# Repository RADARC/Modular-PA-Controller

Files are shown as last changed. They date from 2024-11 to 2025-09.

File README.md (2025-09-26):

# Modular-PA-Controller
Controller for High Power RF Power Amplifiers based Raspberry Pi Pico

Reading and District Amateur Radio Club(RADARC) are working together on a number of collaborative construction projects. This one is to design and build a Modular PA controller for High Power (1kW plus) semiconductor Power amplifiers.
This prototype implementation is targetted on the High Power HF PA Modules from [W6PQL](https://www.w6pql.com/) :

* [Kilowatt PA](https://www.w6pql.com/1_kw_sspa_for_1_8-54_mhz.htm)
* [LPF Filter](https://www.w6pql.com/a_1.5kw_lpf_for_160-6m.htm)
* [Directional Coupler](https://www.w6pql.com/1_8_to_54_mhz_dual_coupler.htm)

## Objectives:
<ul>
<li><strong>Protection</strong></li>
<ul>
<li>Protection of user and premises</li>
<li>Protection of Power Amplifier</li>
<li>Protection of connected equipment</li>
</ul>
<li><strong>Automatic Operation and Sequencing</strong>
<ul>
<li>Monitoring of Power Amplifier operational state</li>
<li>Control of operational components of Power Amplifier</li>
<li>Detection of state of connected equipment</li>
<li>Sequencing and crystal controlled timing of sequencing</li>
</ul>
<li><strong>Power Supplies</strong></li>
<ul>
<li>Low voltage power supplies derived from High Voltage PA supply</li>
<li>Variable Vgg Bias voltage supply</li>
</ul>
<li><strong> External control and Monitoring</strong></li>
<ul>
<li>LCD Display</li>
<li>USB</li>
<li>TTL Serial</li>
<li>Wifi and Bluetooth</li>

</ul>
</ul>

## Specification
<ul>
<li>Processor: Raspberry Pi Pico</li>
<li>Maximum input Voltage: 72V DC</li>
<li>Maximum switched PA current: 50A</li>
<li>Vgg bias output range: 1.4V to 4.7V</li>
<li>Number of PWM and RPM monitored fans(5V or 12V): 3</li>
<li>Number of voltage controlled fans: 1</li>
<li>Number of directional coupler inputs: 3</li>
<li>Analogue meter outputs: 2
<li>Transceiver ALC output: -12V to +12V</li>
<li>Transceiver digital SEND in/out Ports: 1</li>
<li>OLED control ports: 1</li>
<li>Rotary Encoders: 2</li>
<li>OLED control ports: 1</li>
<li>Input frequency measurement range: 100kHz to 50MHz</li>
<li>Input Power detection: 10dBm to 50dBm</li>
<li>Maximum input Power Tx/RX switching: 50dBm</li>
<li>Output TX/RX relay drivers(5V or 12V): 2</li>
<li>Output LPF relay drivers(%V or 12V): 6</li>
<li>I2C ports: 1</li>
<li>TTLserial ports: 1</li>                                                                                               
</ul>

## Hardware Implementation

The Modular PA Controller Is built around four PCB assemblies:

### Power Supply and Control Board
This board manages the high DC voltage (up to 72V) part of the PA controller. It provides switching of the DC supply up to 50A, also current monitoring and Voltage monitoring. The DC supply switching uses a watchdog an requires the processor to signal the switch every 500uS to keep the power on.
It derives two lower voltage power supplies at 12V 2A and 5V 1A. The 3.3V logic supply for th PA controller is provided by the regulator on the Pi Pico on the processor board.To control the Vgg Bias to the Power Amplifier Modules the board provides either a switched 12V supply to a regulator on the Power Amplifier Board, and also a variable voltage software controlled DC output.
All control and monitoring is via I2C control from the Processor Board.

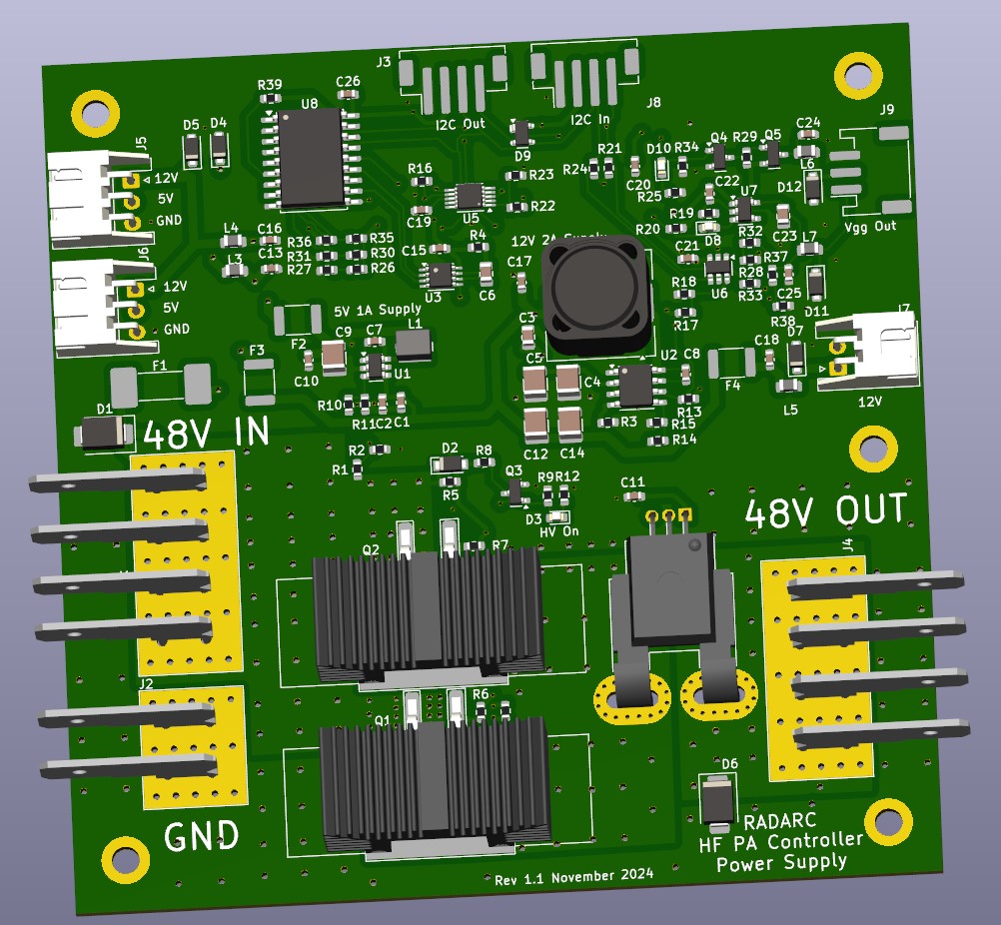
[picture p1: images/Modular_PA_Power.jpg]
Power Supply 3D


[Kicad Files](./Kicad/PA_Power_V1/)

### Processor and Interface Board
This board contains the Raspberry Pi Pico microcontroller module. The module alo provides the 3.3V logic supply and the USB interface. Pi Pico modules with Bluetooth and Wi-fi may be used, also the higher performance RP2350 version.

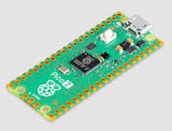
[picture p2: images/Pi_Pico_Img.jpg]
Pi Pico Image


[Pi Pico Data sheet](https://datasheets.raspberrypi.com/pico/pico-datasheet.pdf)

The board has two I2C buses. The internal bus connects to the on board ADC and DAC devices. The external I2C bus connects to the Power Supply and Control board(s), the Relay Driver board(s), LM75 temperature sensors, I2C OLED display, etc.

The board has an input TX/RX relay to bypass the Power Amplifier Modules as required.

### Relay Driver Board

### RF screen

## Software Implementation

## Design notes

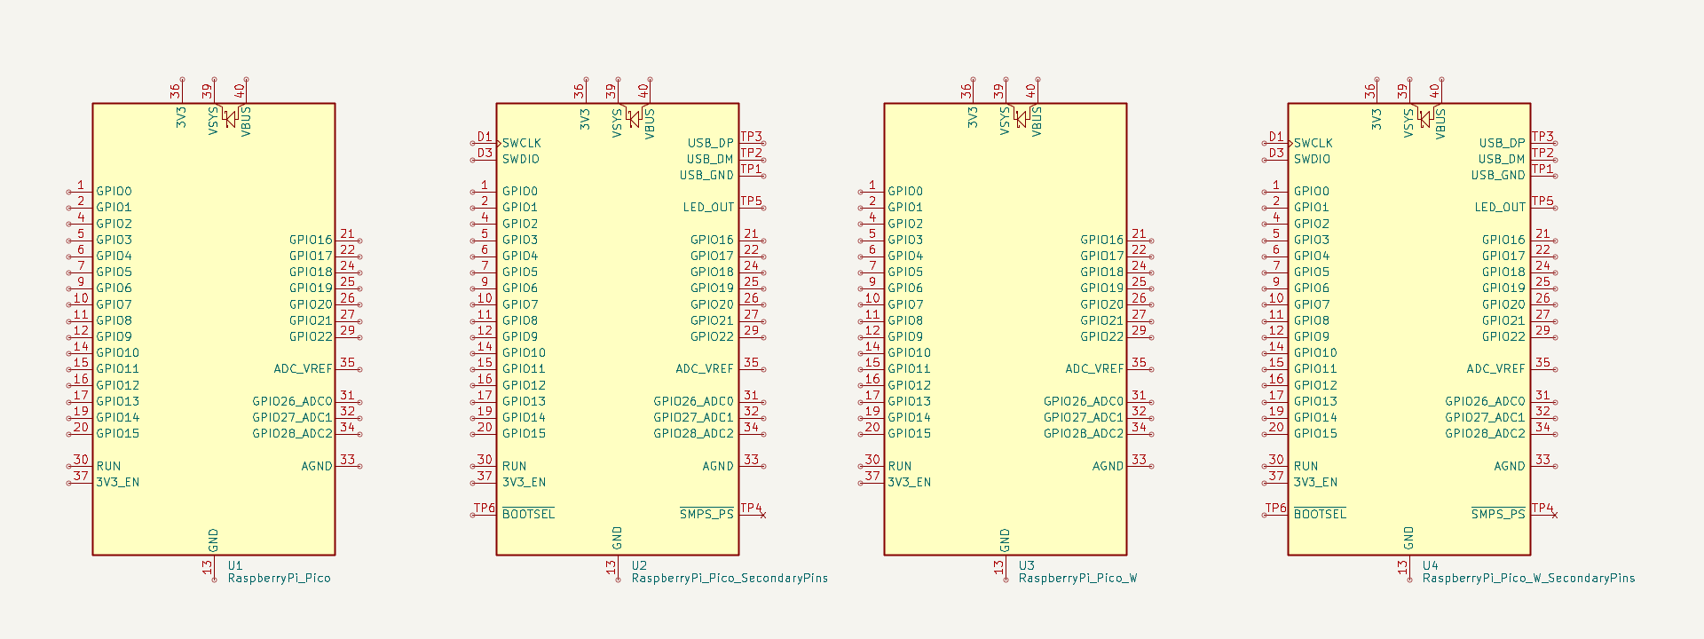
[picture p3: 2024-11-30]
Kicad/PA_Power_V1/RLab Keyboard/ki-lime-pi-pico-2.1.2/_md-assets/images/schematics.png

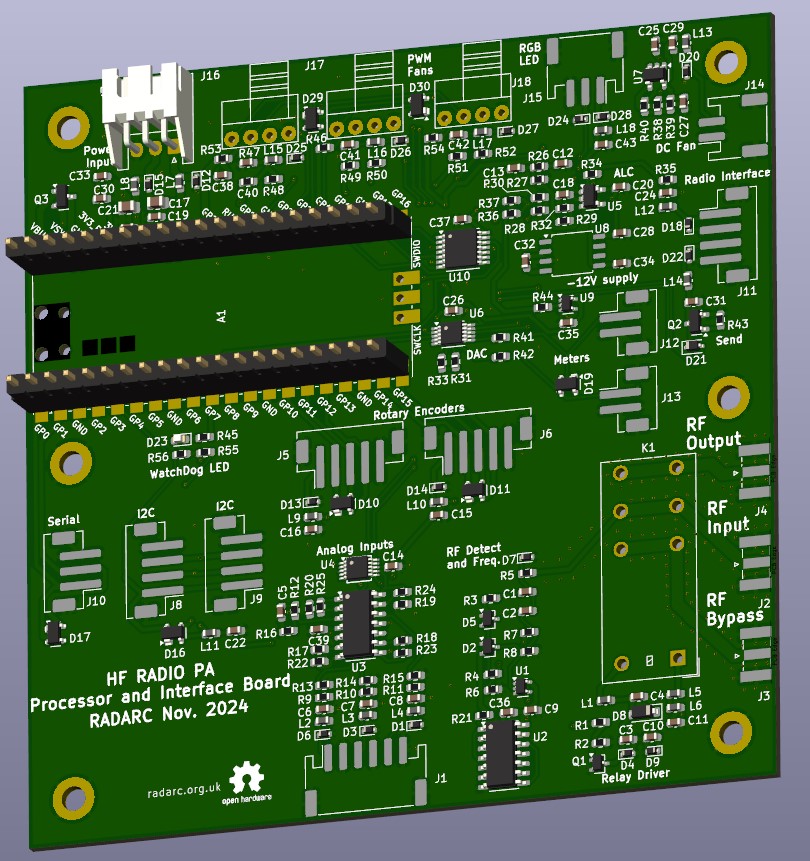
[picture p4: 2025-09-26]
images/Processor.jpg

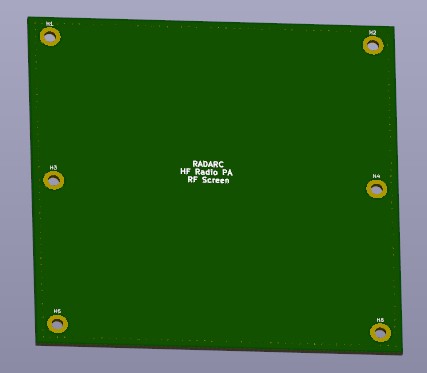
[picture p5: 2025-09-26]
images/RF_Screen.jpg

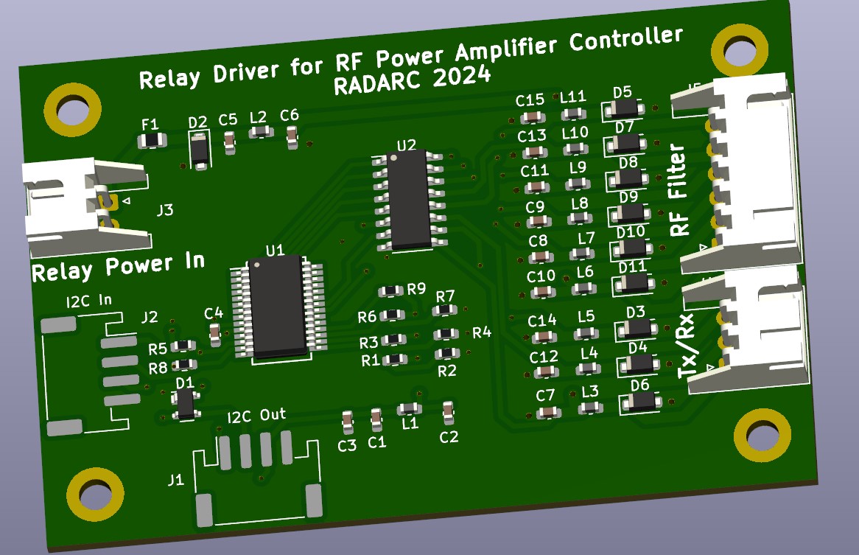
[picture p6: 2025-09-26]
images/Relay Driver.jpg

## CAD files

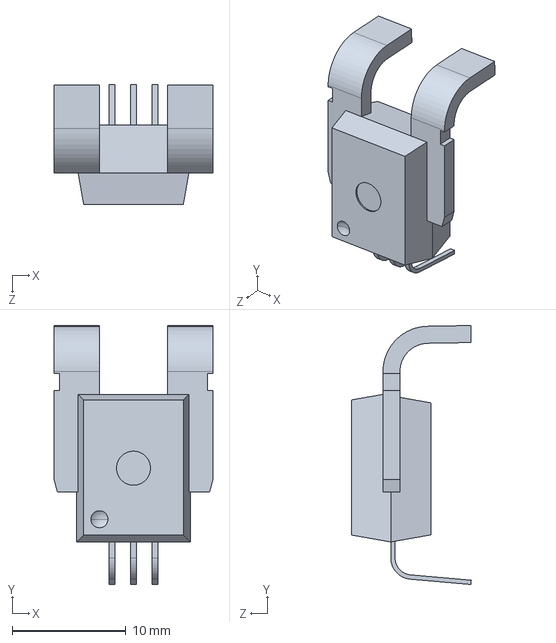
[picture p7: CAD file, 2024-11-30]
Kicad/PA_Power_V1/ACS758LCB-100B-PFF-T.stp
14.0 x 22.8 x 10.5 mm

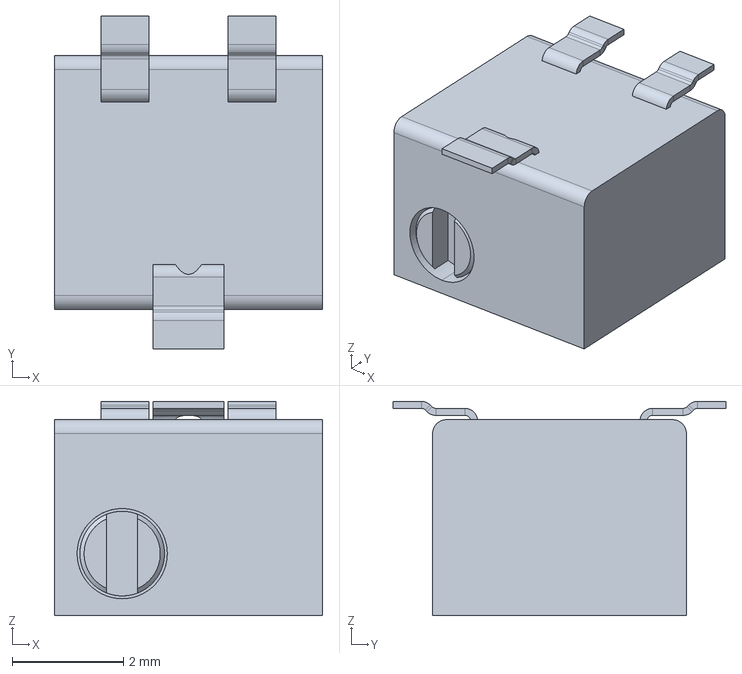
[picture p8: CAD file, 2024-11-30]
Kicad/PA_Power_V1/RLab Keyboard/3D_Models/3214G.stp
4.83 x 5.99 x 3.86 mm

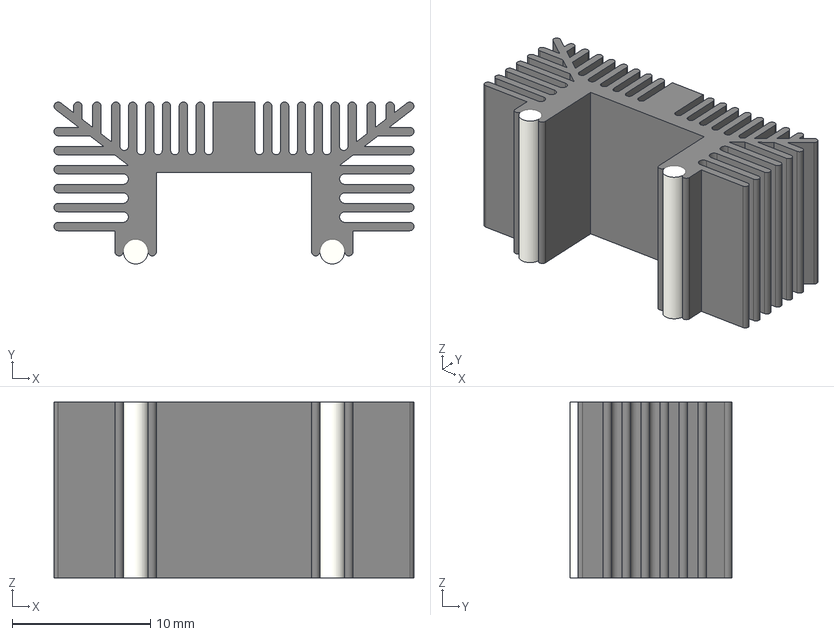
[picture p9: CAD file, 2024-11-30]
Kicad/PA_Power_V1/ohmite_DA-T263-401E-TR.stp
26.0 x 11.7 x 12.7 mm

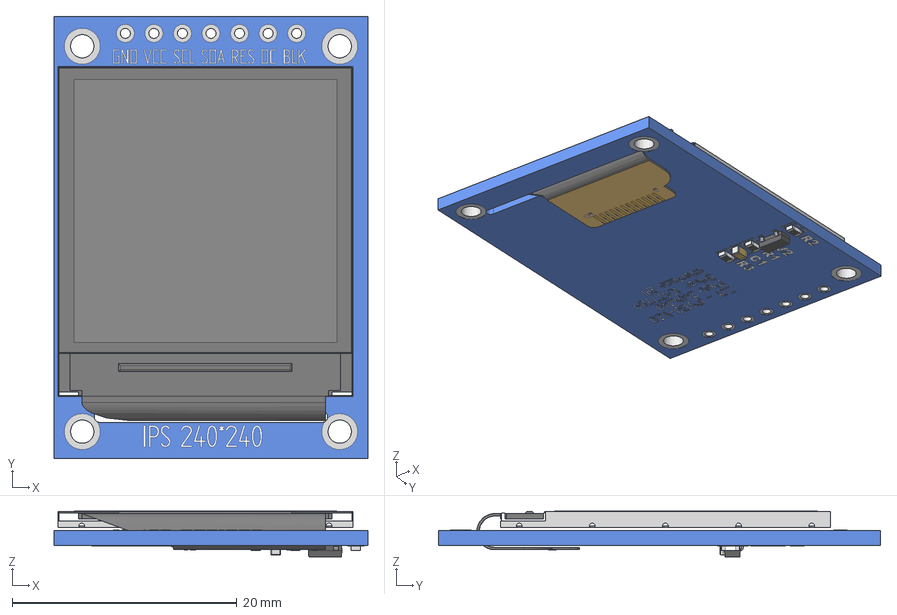
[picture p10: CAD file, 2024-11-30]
Kicad/PA_Power_V1/RLab Keyboard/3D_Models/1.3 TFT IPS.stp
27.9 x 39.4 x 4.06 mm
1.3 TFT IPS - Board
1.3 TFT IPS - Flush Reverse Mount
0603 Resistor x 3
0603 Capacitor
SOT-23

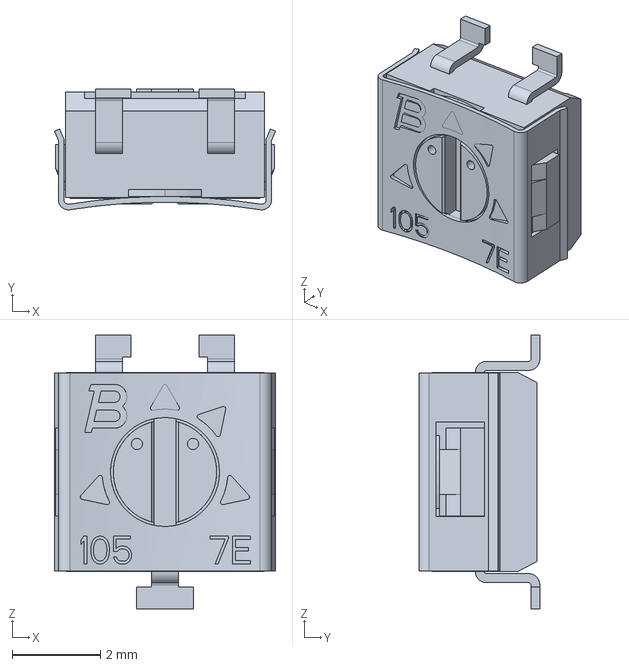
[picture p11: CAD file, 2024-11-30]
Kicad/PA_Power_V1/RLab Keyboard/3D_Models/3314G1.stp
5.00 x 2.73 x 6.20 mm

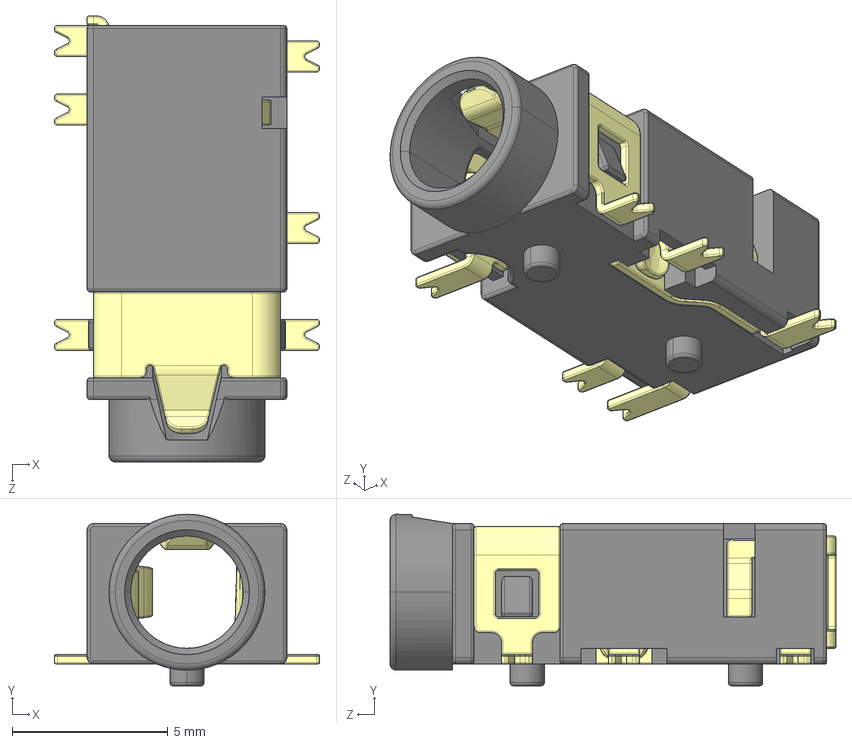
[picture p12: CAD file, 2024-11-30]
Kicad/PA_Power_V1/RLab Keyboard/3D_Models/PJ311D_WPos.STEP
8.50 x 5.50 x 14.3 mm
001^PJ311D_WPos
002^PJ311D_WPos
003^PJ311D_WPos
004^PJ311D_WPos
005^PJ311D_WPos
006^PJ311D_WPos
007^PJ311D_WPos

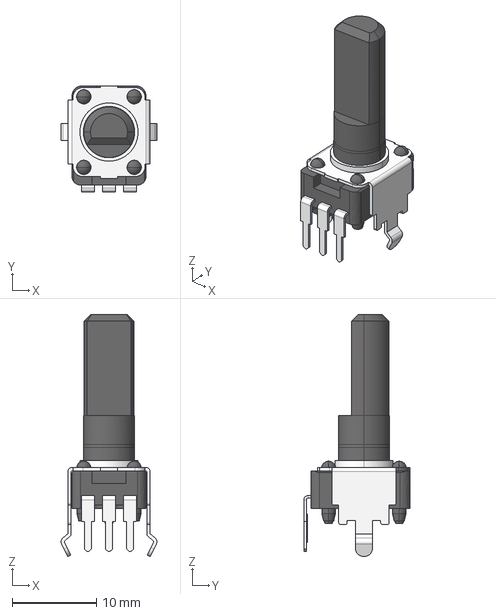
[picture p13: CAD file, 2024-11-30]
Kicad/PA_Power_V1/RLab Keyboard/3D_Models/RK09K1130AH1.STEP
11.4 x 12.7 x 28.8 mm

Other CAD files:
Kicad/PA_Power_V1/RLab Keyboard/KiCad-RP-Pico/SketchUp Model/Pico.skp

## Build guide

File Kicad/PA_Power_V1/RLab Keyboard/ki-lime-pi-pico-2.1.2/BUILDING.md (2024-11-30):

**Instructions for building from source**
===========================================

> *Note that this project was largely leveraged for becoming more familiar with various aspects of KiCad, FreeCAD, and the Raspberry Pi Pico, and certain files may use exploratory workflows as a result.*

&nbsp;

# Development Environment

  Parametric models exported using [FreeCAD 0.21.2](https://github.com/FreeCAD/FreeCAD/releases/tag/0.21.2) with the [KiCad StepUp 12.2.6](https://github.com/easyw/kicadStepUpMod/tree/a7da10da12e405d106e1e9eb551444a289859ee8) workbench addon

  If you plan on committing changes to the .FCStd document and want (somewhat) trackable commits, then from the repository root call:

  ```bash
  mkdir -p .git/hooks
  cp .githooks/pre-commit.sh .git/hooks/pre-commit
  git config --local core.hooksPath .git/hooks
  ```

  *(If you are already using a `pre-commit` git hook, then manually add the content of `pre-commit.sh` to the existing hook instead)*

  > *Copying the file at a known state curbs the security concerns of remote changes to a hook.  Always audit scripts before using them.*

  Exported VRML models modified in [VSCodium 1.74.3](https://github.com/VSCodium/vscodium/releases/tag/1.74.3.23010)

  KiCad symbols and footprints exported using [KiCad 8.0.3](https://github.com/KiCad/kicad-source-mirror/releases/tag/8.0.3)

&nbsp;

# Symbols and Footprints

  KiCad symbols and footprints are already in the appropriate directories, so nothing needs to be done to prepare them for export.

&nbsp;

# Models

<details><summary>Regarding parametric colours</summary>
  
  > *Model faces are parametrically coloured via boolean operations between parts of varying diffuse colours.  To alter source colours for the board, see `Parametric_Source > Boards_Source > Parametric Board Colour Sources` in the `Tree view` panel and modify each Body's `Appearance`.  To alter source colours for components, be sure to modify the `Appearance` of the source Bodies **directly**, which are contained within the compounds/part containers in `Parametric_Source > Pico_Components_Source`.  Modifying the `Appearance` of the compounds/part containers or setting parts' face colours with `Set Colors...` will **not** parametrically populate.*
  >
  > *Note that as of FreeCAD 0.20.2 changing the sources of the colours does not automatically populate down all the dependent objects.  To get around this if you make any colour changes, when you are ready to export be sure to recompute the entire document as detailed below.  This should successfully populate the parametric colours across all dependent objects.*
  
</details>

  ### General

  - Open the models source file at `.../ki-lime-pi-pico/models/RaspberryPi_Pico_Variations.FCStd` in FreeCAD

    > Note: ~~If reproducible builds are important, be sure to stash any local changes to the file and reopen it before building so that you are recomputing from a known commit.~~  
    > ~~This is particularly important if you are using the `pre-commit` git hook described above.~~  
    > There is inconsistent noise generated with each recompute/export.  As a result, reproducible builds are not possible as built models will slightly differ each time.
  
  - If not already marked to recompute, in FreeCAD's `Tree view` panel `right-click` on the root document name `RaspberryPi_Pico_Variations` and select `Mark to recompute`

  - Click `Edit > Refresh` (or press `F5`) to recompute the entire document

  ### VRML

  - Enter the KiCad StepUp addon workbench from the drop-down menu at the top of the window

  - In FreeCAD's `Tree view` panel, locate the contents of the folder `Export > KiCad Model Outputs > VRML - Manually Coloured Clones`

  - If you are building from an official release commit, select the `Clone` you wish to export to a VRML file for KiCad (for example: `RaspberryPi_Pico`)  
    If you are building from a custom modification, you will likely need to recreate the `Draft Clones` from the parametrically coloured `Compounds` in `Export > KiCad Model Outputs > STEP - Parametrically Coloured Compounds`

    <details><summary>Additional information regarding clones and colours</summary>
      
      > *KiCad StepUp provides a selection of fully-featured materials that can be exported to VRML files.  Although the selection is limited, it provides convenient labelling of materials that can be edited later.  I have created `Clones` of each variation (which as of FreeCAD 0.20.2 do **not** parametrically preserve colour) and pre-set each face colour to align with colours defined within KiCad StepUp.*
      >
      > *Note that if you change geometry in any way which alters the number or topological location of faces anywhere within the model, these pre-set `Clones` will no longer be coloured appropriately*
      >
      > *You can always export from the parametrically coloured `Compounds` in `Export > KiCad Model Outputs > STEP - Parametrically Coloured Compounds`, just needing to set the export colours in KiCad StepUp each time as they will be reset upon recomputes.*
      
    </details>

  - Click on KiCad StepUp's `Export 3D Model` button (a graphic of a black 6-pin IC with a green arrow pointing down and to the right)

  - When prompted, I have used the values of `0.03 Mesh Deviation` and `0.5 creaseAngle` (old default values) and I find the results to be acceptable

  - If you are building from an official release commit, simply accept all the KiCad StepUp colour association prompts  
    If you are building from newly created `Clones`, you will need to manually set KiCad StepUp's colour associations.
    
    <details> <summary> Additional information regarding KiCad StepUp colour association </summary>
    
      > This part can be frustrating, as many parts appear off-white but are different materials.
      > When I built it, there are some colours which are automatically associated to a named material in KiCad StepUp; you shouldn't have to alter those.  
      > The remaining non-automatic colours broadly presented themselves in the following order:
      >
      > - `metal silver` (soldered pads)
      > - `pcb green`
      > - `light brown label` (FR4 core)
      > - `yellow body` (gold pins)
      > - `brown body` (caps)
      > - `resistor black body` (res/diode)
      > - `led white` (led lens)
      > - `light brown body` (led board)
      > - `green body` (led phosphor)
      > - `metal grey` (oscillator/wifi package)
      >
      > If this list doesn't appear to be accurate for you, then you can always set each colour to a high-contrasting material, and then select the appropriate material association in a second round of exporting.

    </details>

  - Repeat this for all `Clones`

  - Prepare a powerful text editor for bulk file editing

    <details> <summary> Specific instructions for preparing VSCodium/VSCode</summary>

      - Open a new VSCode-based instance

      - Select `File > Open Folder...`

      - Navigate to the directory `.../ki-lime-pi-pico/`

      - Select the folder `models/` and click `Select Folder`

      - Open each `.wrl` file by `double-clicking` each file in the `Explorer` pane

      - Select the magnifying glass on the left to open the `Search` pane

      - Expand the search box with the arrow to its left to reveal its find-and-replace functionality

      - Click the `...` in the bottom-right of the find-and-replace fields to expand additional options

      - Select the graphic of an open book in the `files to include` field to only process files which are currently open

    </details>

  - Find and replace the following material names in the newly created `.wrl` files:

    > *Be sure **not** to replace these material names in `MaterialsList.txt`!*

    | Original material   | Replace with
    |:-------------------:|:------------:
    | `PLASTIC-YELLOW-01` | `FINISH-GOLD`
    | `MET-SILVER`        | `FINISH-SILVER`
    | `RES-SMD-01`        | `IC-BODY-EPOXY-02`
    | `CAP-CERAMIC-06`    | `CAP-CERAMIC-01`
    | `MET-01`            | `FINISH-TIN`
    | `IC-LABEL-01`       | `BOARD-FR4-NATURAL`
    | `BOARD-GREEN-02`    | `MASK-PINE-GREEN`
    | `RES-THT-01`        | `MASK-LIGHT-TAN`
    | `LED-WHITE`         | `LED-LENS-CLEAR`
    | `PLASTIC-GREEN-01`  | `EMISSIVE-GREEN-PHOSPHOR`
  ##  
  - Finally, replace the default KiCad StepUp material definitions at the start of each `.wrl` file with the expanded list of materials found in `MaterialsList.txt`

    > *In VSCode-based editors, selecting `Match Case` in the search allows for the large blocks of material definition text to successfully be found and replaced*

    ---

  &nbsp;

  > *KiCad StepUp will automatically generate STEP files with limited hierarchy, part naming, and colour information as a result of the process above, so next we will export STEP models with more detailed information.*

  > *As of the time of writing, KiCad does not appropriately handle exporting part face colours when the component's STEP file uses assemblies.  To get around this, we will export our STEP models as `Compounds` for KiCad.  This will still result in limited hierarchy and part naming information, but will at least preserve face colours (excluding transparency) and discrete sub-components.*

  ### STEP (for KiCad)

  - In FreeCAD's `Tree view` panel, shift focus to the contents of the folder `Export > KiCad Model Outputs > STEP - Parametrically Coloured Compounds`

  - Manually select the root body you wish to export (for example: `RaspberryPi_Pico_Compound`)

  - Press `Ctrl + E`, or select `File > Export`

  - For ease, ensure the directory matches where KiCad StepUp exported its files to:
    `.../ki-lime-pi-pico/models/`

  - Ensure file type `"STEP with colors (*.step *.stp)"` is selected

  - Select the name of the already-generated model you intend to replace (for example: `RaspberryPi_Pico.step`)

  - Select `Save`, and select `Yes` when asked to replace the existing file

  - Repeat this for all models

  - Once all 3D models have been exported as `.wrl` and `.step` files, navigate to:

  ```
  .../ki-lime-pi-pico/models/
  ```

  - And **copy** (don't remove!) all `.wrl` and `.step` files to:

  ```
  .../ki-lime-pi-pico/kicad/project-libraries/RaspberryPi_Pico/Module_RaspberryPi_Pico.3dshapes/
  ```

  ---
  > *In addition to these KiCad models, we can also export a second set of STEP files to a supplemental directory, in the event any users have a need for the fully-featured assemblies.  Feel free to skip this section if all you need is a standalone KiCad library.*

  ### STEP (fully featured supplement)

  - In FreeCAD's `Tree view` panel, navigate into the folder `Export > STEP Assembly`

  - Manually select the root body you wish to export (for example: `RaspberryPi_Pico_STEP`)

  - Press `Ctrl + E`, or select `File > Export`

  - For ease, ensure again the directory matches where KiCad StepUp exported its files to:
    `.../ki-lime-pi-pico/models/`

  - Ensure file type `"STEP with colors (*.step *.stp)"` is selected

  - Select the name of the already-generated model you intend to replace again (for example: `RaspberryPi_Pico.step`)

  - Select `Save`, and select `Yes` when asked to replace the existing file

    > *As a result of using empty `Group` folders as a source of parametric part/feature naming, exporting these parts will result in an expected warning in the `Report view`.*

  - Repeat this for all models

  - Once these 3D models have been exported as `.step` files, navigate to:
  ```
  .../ki-lime-pi-pico/models/
  ```

  - And copy all `.step` files to:

  ```
  .../ki-lime-pi-pico/models/RaspberryPi_Pico_STEP/
  ```

  ### File cleanup

  - Navigate to `.../ki-lime-pi-pico/models/`

  - Delete the previously copied `.wrl` and `.step` files, as they are no longer needed in this directory

&nbsp;

# Final recommendations

As desired, navigate to our source's root directory:

```
.../ki-lime-pi-pico/
```

Append, replace, or otherwise modify files such as `LICENSE.txt`, `ATTRIBUTION.md`, and `README.md` to appropriately reflect your needs.

Copy the desired files *(for example, I include all three of `LICENSE.txt`, `ATTRIBUTION.md`, and `README.md` with the final build)* to:

```
.../ki-lime-pi-pico/kicad/project-libraries/RaspberryPi_Pico/
```

*I prefer to remove the references to images in the built library's `README.md` once it's copied here to keep it clean and compact.*

If you are also exporting the fully-featured supplemental STEP models, copy the desired files *(for example, I include `LICENSE.txt` and `ATTRIBUTION.md`)* to:

```
.../ki-lime-pi-pico/models/RaspberryPi_Pico_STEP/
```

&nbsp;

# **All done!** 🎉

Your completed library to reference, copy, and distribute as you wish can be found at:

```
.../ki-lime-pi-pico/kicad/project-libraries/RaspberryPi_Pico/
```

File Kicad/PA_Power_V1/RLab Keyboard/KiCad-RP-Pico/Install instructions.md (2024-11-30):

# Install instructions

## 1. Copy the files locally

Copy the `RP-Pico Libraries` folder wherever you like on your computer.

## 2. Install the Raspberry Pi Pico board schema symbol

Use the `KiCad | Preferences | Manage Symbol Libraries...` command to manage the symbol library:



then select the global tab and click on the folder button:



navigate to the `RP-Pico Libraries` folder, select the `MCU_RaspberryPi_and_Boards.kicad_sym` file and open it:



et voilà, the first step is completed:



You can now close the symbol libraries manager window.

## 3. Install the Raspberry Pi Pico board footprint

You can use a similar approach to add the footprint to the footprint libraries manager, but I've found some issues that I've solved using the footprint editor, so here are the steps I suggest you to follow:

Open the footprint editor



wait for the footprints to load... then use the `File | Add Library` command:



confirm the `Global` choice:



and select the `MCU_RaspberriPi_and_Boards.pretty` folder (yes, the folder represent a footprint library on KiCad):



Now the library is installed on KiCad with the Raspberry Pi Pico footprint (double click on it to see it on the editor pane):



Don't close the windows as the next step start from here.

## 4. Install the Raspberry Pi Pico board footprint 3D visual

If not already open, open the the footprint editor

symbol library manager

double click on the `RPi_Pico_SMD_TH` footprint from the `MCU_RaspberriPi_and_Boards` library and then click on the `Footprint properties` icon:



In the footprint properties window, first select the `3D Settings` tab. Please note that the preview shows only the PCB board with the footprint added on step 3, without any 3D representation of the Raspberry Pi Pico board. Now click on the folder icon to add the 3D model:



Navigate to the `RP-Pico Libraries` folder, select the `Pico.wrl` file and wait until the model is shown in the right panel, then confirm with OK:



The model is already scaled and translated to match the footprint:



now close the `Footprint Properties` window, and the `Footprint Editor`, obviously saving the changes.

## Conclusion

Now that you've installed the schema and footprint and added the 3D model to the footprint, you can use the Raspberry Pi Pico board on your KiCad projects.

I've also added a test KiCad Project on the `Test` folder, that you can use to see an example of it.

Have fun!

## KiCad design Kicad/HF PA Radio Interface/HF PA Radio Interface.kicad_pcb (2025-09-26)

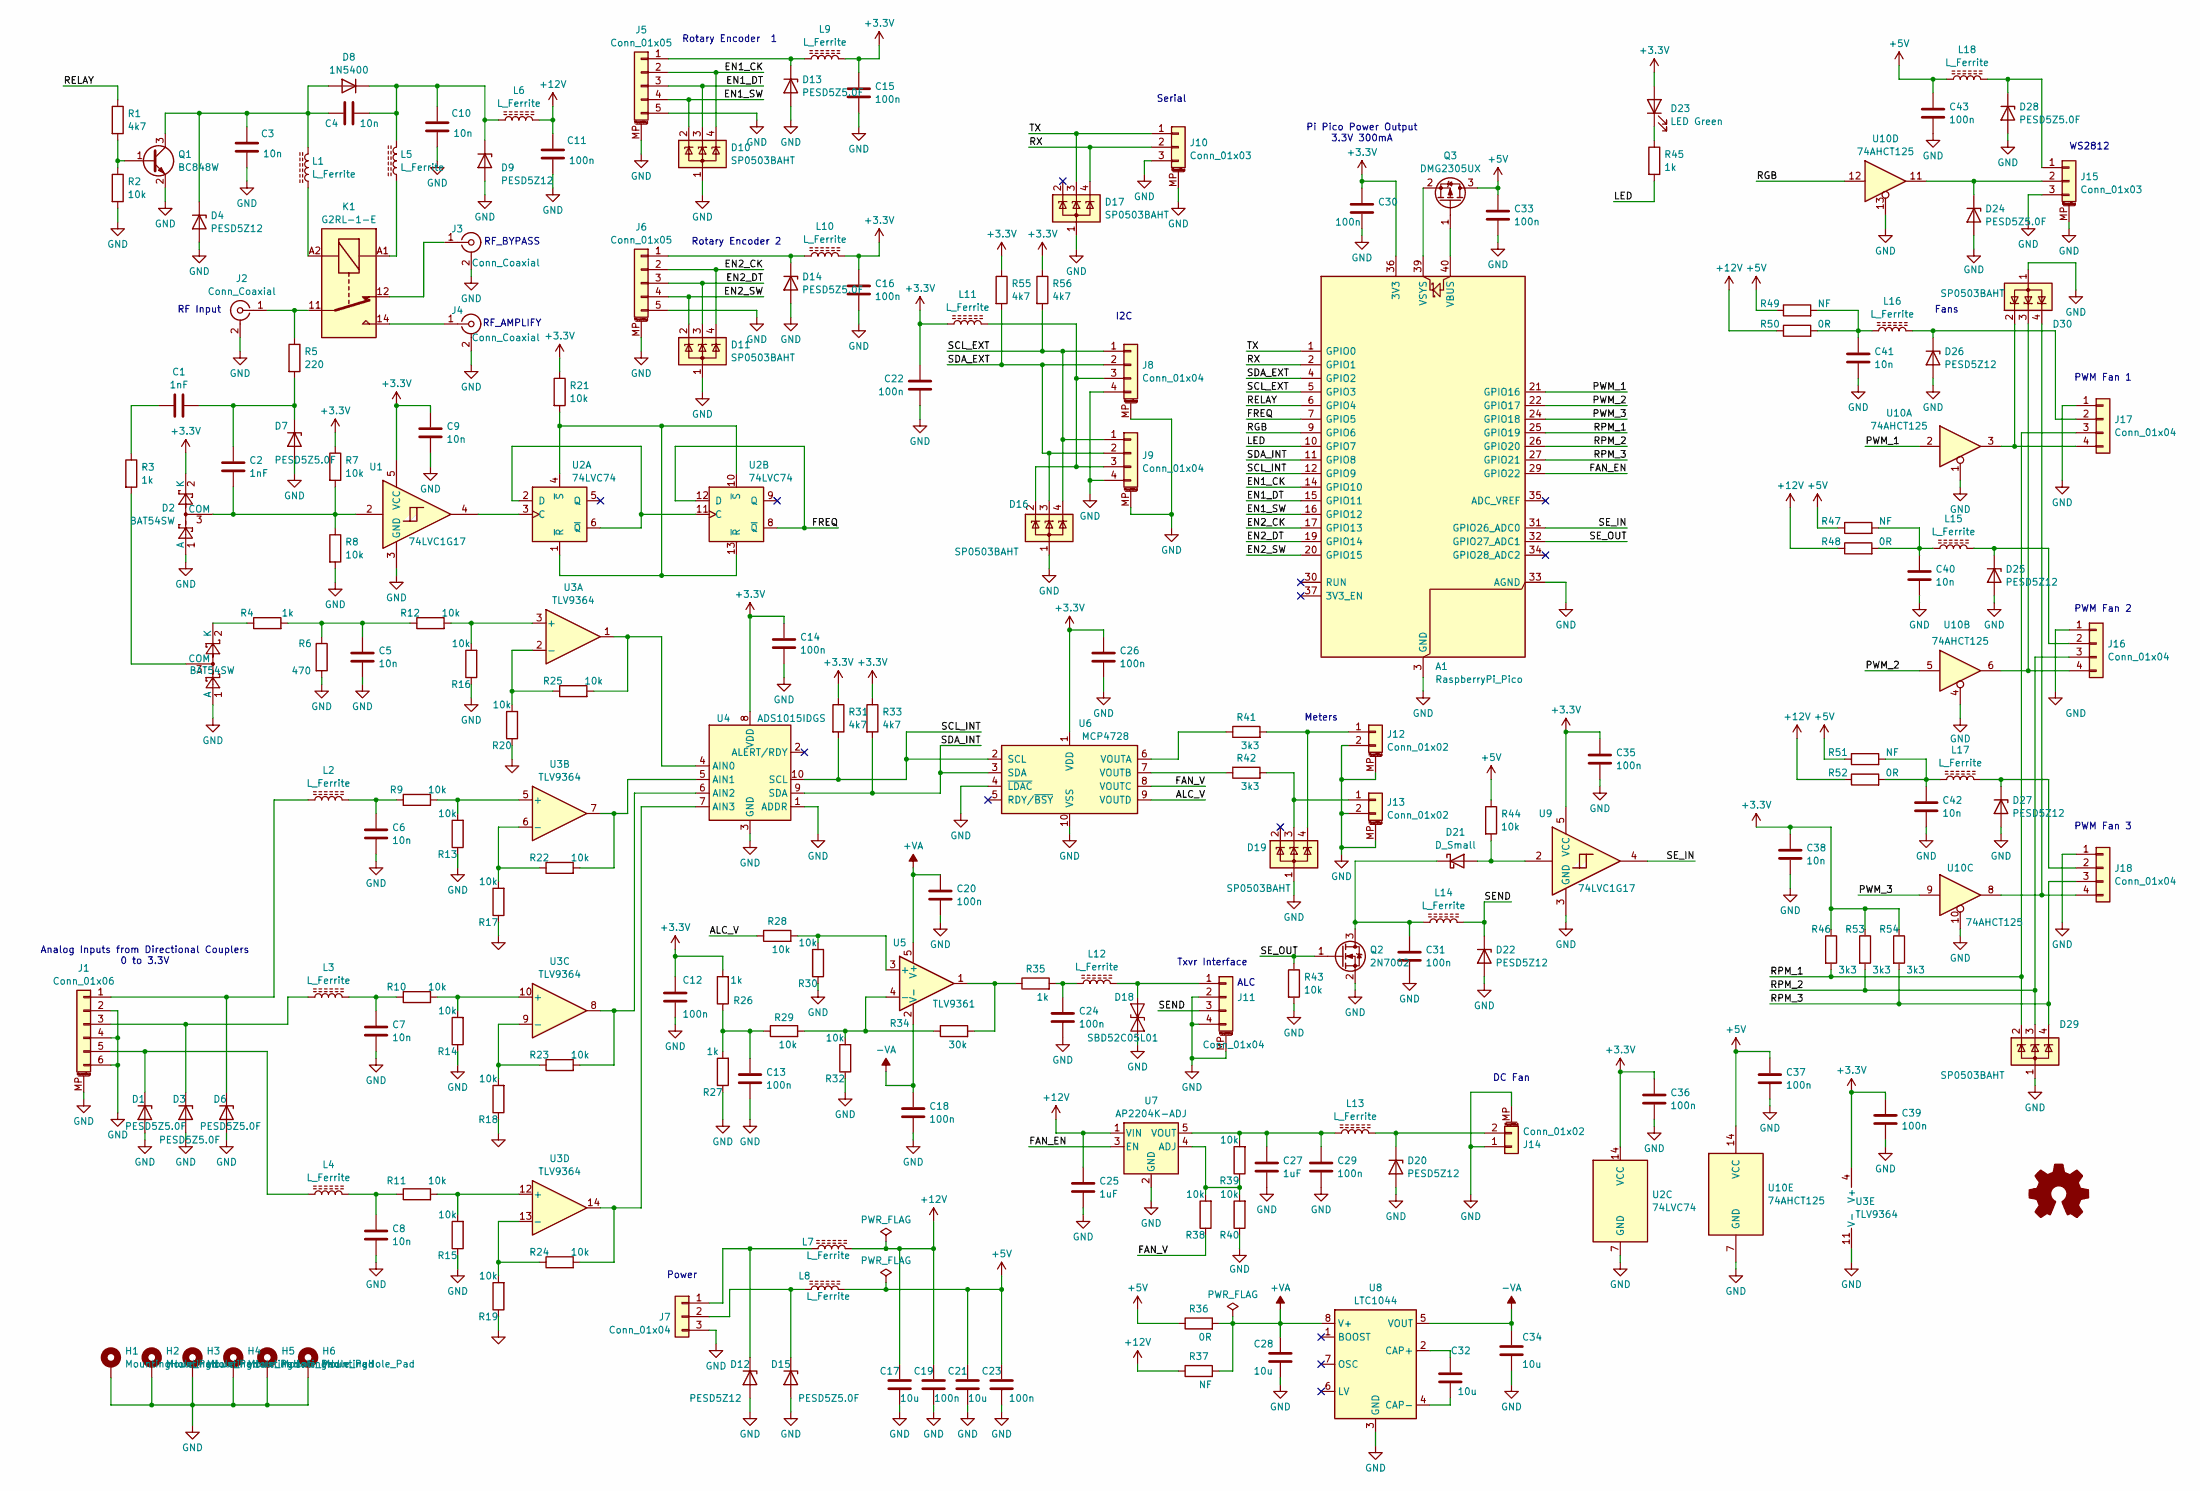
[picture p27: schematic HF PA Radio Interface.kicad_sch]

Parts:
A1: RaspberryPi_Pico; RPi_Pico_SMD_TH
C1, C2: 1nF; C_0603_1608Metric
C3, C4, C5, C6, C7, C8, C9, C10, C38, C40, C41, C42: 10n; C_0603_1608Metric
C11, C12, C13, C14, C15, C16, C18, C19, C20, C22, C23, C24, C26, C29, C30, C31, C33, C35, C36, C37, C39, C43: 100n; C_0603_1608Metric
C17, C21: 10u; C_0805_2012Metric
C25, C27: 1uF; C_0603_1608Metric
C28, C32, C34: 10u; C_0603_1608Metric
D1, D3, D6, D7, D13, D14, D15, D24, D28: PESD5Z5.0F; D_SOD-523
D2, D5: BAT54SW; SOT-323_SC-70
D4, D9, D12, D20, D22, D25, D26, D27: PESD5Z12; D_SOD-523
D8: 1N5400; D_SOD-123
D10, D11, D16, D17, D19, D29, D30: SP0503BAHT; SOT-143
D18: SBD52C05L01; D_SOD-523
D21: D_Small; D_SOD-323
D23: LED Green; LED_0603_1608Metric
H1, H2, H3, H4, H5, H6: MountingHole_Pad; MountingHole_3.2mm_M3_DIN965_Pad
J1: Conn_01x06; JST_PH_S6B-PH-SM4-TB_1x06-1MP_P2.00mm_Horizontal
J2, J3, J4: Conn_Coaxial; SMA_Samtec_SMA-J-P-X-ST-EM1_EdgeMount
J5, J6: Conn_01x05; JST_PH_B5B-PH-SM4-TB_1x05-1MP_P2.00mm_Vertical
J7: Conn_01x04; JST_XH_S3B-XH-A_1x03_P2.50mm_Horizontal
J8, J9, J11: Conn_01x04; JST_PH_B4B-PH-SM4-TB_1x04-1MP_P2.00mm_Vertical
J10: Conn_01x03; JST_PH_B3B-PH-SM4-TB_1x03-1MP_P2.00mm_Vertical
J12, J13: Conn_01x02; JST_PH_B2B-PH-SM4-TB_1x02-1MP_P2.00mm_Vertical
J14: Conn_01x02; JST_PH_S2B-PH-SM4-TB_1x02-1MP_P2.00mm_Horizontal
J15: Conn_01x03; JST_PH_S3B-PH-SM4-TB_1x03-1MP_P2.00mm_Horizontal
J16, J17, J18: Conn_01x04; KF2510-4AW_3+1P
K1: G2RL-1-E; Relay_SPDT_Omron_G2RL-1-E
L1, L2, L3, L4, L5, L6, L7, L8, L9, L10, L11, L12, L13, L14, L15, L16, L17, L18: L_Ferrite; L_0603_1608Metric
Q1: BC848W; SOT-323_SC-70
Q2: 2N7002; SOT-23
Q3: DMG2305UX; SOT-23
R1, R31, R33, R55, R56: 4k7; R_0603_1608Metric
R2, R7, R8, R9, R10, R11, R12, R13, R14, R15, R16, R17, R18, R19, R20, R21, R22, R23, R24, R25, R28, R29, R30, R32, R38, R39, R40, R43, R44: 10k; R_0603_1608Metric
R3, R4, R26, R27, R35, R45: 1k; R_0603_1608Metric
R5: 220; R_0603_1608Metric
R6: 470; R_0603_1608Metric
R34: 30k; R_0603_1608Metric
R36, R48, R50, R52: 0R; R_0603_1608Metric
R37, R47, R49, R51: NF; R_0603_1608Metric
R41, R42, R46, R53, R54: 3k3; R_0603_1608Metric
SYM1: Logo_Open_Hardware_Small; OSHW-Logo2_7.3x6mm_SilkScreen
U1, U9: 74LVC1G17; SOT-353_SC-70-5
U2: 74LVC74; SOIC-14_3.9x8.7mm_P1.27mm
U3: TLV9364; SOIC-14_3.9x8.7mm_P1.27mm
U4: ADS1015IDGS; TSSOP-10_3x3mm_P0.5mm
U5: TLV9361; SOT-23-5
U6: MCP4728; MSOP-10_3x3mm_P0.5mm
U7: AP2204K-ADJ; SOT-23-5
U8: LTC1044; SOIC-8_5.23x5.23mm_P1.27mm
U10: 74AHCT125; TSSOP-14_4.4x5mm_P0.65mm

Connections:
+3.3V: A1.36 (3V3), C9.1, C12.1, C14.1, C15.1, C16.1, C22.1, C26.1, C30.1, C35.1, C36.1, C38.1, C39.1, D2.2 (K), D23.2 (A), L9.2, L10.2, L11.2, R7.1, R21.1, R26.2, R31.1, R33.1, R46.1, R53.1, R54.1, R55.1, R56.1, U1.5 (VCC), U2.14 (VCC), U3.4 (V+), U4.8 (VDD), U6.1 (VDD), U9.5 (VCC)
+5V: C21.1, C23.1, C33.1, C37.1, C43.1, L8.2, L18.1, Q3.3 (D), R36.1, R44.1, R47.1, R49.1, R51.1, U10.14 (VCC)
+12V: C11.1, C17.1, C19.1, C25.1, L6.2, L7.2, R37.1, R48.1, R50.1, R52.1, U7.1 (VIN)
+VA: C20.1, C28.1, R36.2, R37.2, U5.5 (V+), U8.8 (V+)
-VA: C18.1, C34.1, U5.2 (V-), U8.5 (VOUT)
/ALC_V: R28.1, U6.9 (VOUTD)
/EN1_CK: A1.14 (GPIO10), D10.4 (K), J5.2
/EN1_DT: A1.15 (GPIO11), D10.3 (K), J5.3
/EN1_SW: A1.16 (GPIO12), D10.2 (K), J5.4
/EN2_CK: A1.17 (GPIO13), D11.4 (K), J6.2
/EN2_DT: A1.19 (GPIO14), D11.3 (K), J6.3
/EN2_SW: A1.20 (GPIO15), D11.2 (K), J6.4
/FAN_EN: A1.29 (GPIO22), U7.3 (EN)
/FAN_V: R38.1, U6.8 (VOUTC)
/FREQ: A1.7 (GPIO5), U2.8 (~Q), U2.12 (D)
/LED: A1.10 (GPIO7), R45.2
/PWM_1: A1.21 (GPIO16), U10.2
/PWM_2: A1.22 (GPIO17), U10.5
/PWM_3: A1.24 (GPIO18), U10.9
/RELAY: A1.6 (GPIO4), R1.1
/RGB: A1.9 (GPIO6), U10.12
/RPM_1: A1.25 (GPIO19), D29.2 (K), J17.3, R46.2
/RPM_2: A1.26 (GPIO20), D29.3 (K), J16.3, R53.2
/RPM_3: A1.27 (GPIO21), D29.4 (K), J18.3, R54.2
/RX: A1.2 (GPIO1), D17.4 (K), J10.2
/SCL_EXT: A1.5 (GPIO3), D16.4 (K), J8.1, J9.1, R56.2
/SCL_INT: A1.12 (GPIO9), R31.2, U4.10 (SCL), U6.2 (SCL)
/SDA_EXT: A1.4 (GPIO2), D16.3 (K), J8.2, J9.2, R55.2
/SDA_INT: A1.11 (GPIO8), R33.2, U4.9 (SDA), U6.3 (SDA)
/SEND: D22.1 (K), J11.3, L14.2
/SE_IN: A1.31 (GPIO26_ADC0), U9.4
/SE_OUT: A1.32 (GPIO27_ADC1), Q2.1 (G), R43.1
/TX: A1.1 (GPIO0), D17.3 (K), J10.1
GND: A1.3 (GND), A1.8 (GND), A1.13 (GND), A1.18 (GND), A1.23 (GND), A1.28 (GND), A1.33 (AGND), A1.38 (GND), C3.2, C5.2, C6.2, C7.2, C8.2, C9.2, C10.2, C11.2, C12.2, C13.2, C14.2, C15.2, C16.2, C17.2, C18.2, C19.2, C20.2, C21.2, C22.2, C23.2, C24.2, C25.2, C26.2, C27.2, C28.2, C29.2, C30.2, C31.2, C33.2, C34.2, C35.2, C36.2, C37.2, C38.2, C39.2, C40.2, C41.2, C42.2, C43.2, D1.2 (A), D2.1 (A), D3.2 (A), D4.2 (A), D5.1 (A), D6.2 (A), D7.2 (A), D9.2 (A), D10.1 (A), D11.1 (A), D12.2 (A), D13.2 (A), D14.2 (A), D15.2 (A), D16.1 (A), D17.1 (A), D18.1 (A1), D19.1 (A), D20.2 (A), D22.2 (A), D24.2 (A), D25.2 (A), D26.2 (A), D27.2 (A), D28.2 (A), D29.1 (A), D30.1 (A), H1.1, H2.1, H3.1, H4.1, H5.1, H6.1, J1.2, J1.4, J1.6, J1.MP (MountPin), J2.2 (Ext), J3.2 (Ext), J4.2 (Ext), J5.5, J5.MP (MountPin), J6.5, J6.MP (MountPin), J7.3, J8.4, J8.MP (MountPin), J9.4, J9.MP (MountPin), J10.3, J10.MP (MountPin), J11.2, J11.4, J11.MP (MountPin), J12.2, J12.MP (MountPin), J13.2, J13.MP (MountPin), J14.1, J14.MP (MountPin), J15.3, J15.MP (MountPin), J16.1, J17.1, J18.1, Q1.2 (E), Q2.2 (S), R2.2, R6.2, R8.2, R13.1, R14.1, R15.1, R16.1, R17.1, R18.1, R19.1, R20.1, R27.1, R30.1, R32.1, R40.1, R43.2, U1.3 (GND), U2.7 (GND), U3.11 (V-), U4.1 (ADDR), U4.3 (GND), U6.4 (~LDAC), U6.10 (VSS), U7.2 (GND), U8.3 (GND), U9.3 (GND), U10.1, U10.4, U10.7 (GND), U10.10, U10.13
unnamed: A1.40 (VBUS), Q3.1 (G)
unnamed: A1.39 (VSYS), Q3.2 (S)
unnamed: C1.2, R3.1
unnamed: C5.1, R4.2, R6.1, R12.1
unnamed: C6.1, L2.2, R9.1
unnamed: C7.1, L3.2, R10.1
unnamed: C8.1, L4.2, R11.1
unnamed: C13.1, R26.1, R27.2, R29.1
unnamed: C24.1, L12.1, R35.2
unnamed: C40.1, L15.1, R47.2, R48.2
unnamed: C41.1, L16.1, R49.2, R50.2
unnamed: C42.1, L17.1, R51.2, R52.2
unnamed: D1.1 (K), J1.5, L4.1
unnamed: C2.2, D2.3 (COM), R7.2, R8.1, U1.2
unnamed: D3.1 (K), J1.3, L3.1
unnamed: C3.1, C4.1, D4.1 (K), D8.2 (A), L1.2, Q1.3 (C)
unnamed: D5.3 (COM), R3.2
unnamed: D5.2 (K), R4.1
unnamed: D6.1 (K), J1.1, L2.1
unnamed: C1.1, C2.1, D7.1 (K), R5.2
unnamed: C4.2, C10.1, D8.1 (K), D9.1 (K), L5.2, L6.1
unnamed: D12.1 (K), J7.1, L7.1
unnamed: D13.1 (K), J5.1, L9.1
unnamed: D14.1 (K), J6.1, L10.1
unnamed: D15.1 (K), J7.2, L8.1
unnamed: D18.2 (A2), J11.1, L12.2
unnamed: D20.1 (K), J14.2, L13.2
unnamed: D21.2 (A), R44.2, U9.2
unnamed: C31.1, D21.1 (K), L14.1, Q2.3 (D)
unnamed: D23.1 (K), R45.1
unnamed: D24.1 (K), J15.2, U10.11
unnamed: D25.1 (K), J16.2, L15.2
unnamed: D26.1 (K), J17.2, L16.2
unnamed: D27.1 (K), J18.2, L17.2
unnamed: D28.1 (K), J15.1, L18.2
unnamed: J2.1 (In), K1.11, R5.1
unnamed: J3.1 (In), K1.12
unnamed: J4.1 (In), K1.14
unnamed: D16.2 (K), J8.3, J9.3, L11.1
unnamed: D19.4 (K), J12.1, R41.2
unnamed: D19.3 (K), J13.1, R42.2
unnamed: D30.3 (K), J16.4, U10.6
unnamed: D30.2 (K), J17.4, U10.3
unnamed: D30.4 (K), J18.4, U10.8
unnamed: K1.A1, L5.1
unnamed: K1.A2, L1.1
unnamed: Q1.1 (B), R1.2, R2.1
unnamed: R34.2, R35.1, U5.1
unnamed: U1.4, U2.3 (C)
unnamed: U2.2 (D), U2.6 (~Q), U2.11 (C)
unnamed: R21.2, U2.1 (~R), U2.4 (~S), U2.10 (~S), U2.13 (~R)
unnamed: R12.2, R16.2, U3.3 (+)
unnamed: R20.2, R25.1, U3.2 (-)
unnamed: R9.2, R13.2, U3.5 (+)
unnamed: R17.2, R22.1, U3.6 (-)
unnamed: R10.2, R14.2, U3.10 (+)
unnamed: R18.2, R23.1, U3.9 (-)
unnamed: R11.2, R15.2, U3.12 (+)
unnamed: R19.2, R24.1, U3.13 (-)
unnamed: R25.2, U3.1, U4.4 (AIN0)
unnamed: R22.2, U3.7, U4.5 (AIN1)
unnamed: R23.2, U3.8, U4.6 (AIN2)
unnamed: R24.2, U3.14, U4.7 (AIN3)
unnamed: R28.2, R30.2, U5.3 (+)
unnamed: R29.2, R32.2, R34.1, U5.4 (-)
unnamed: R41.1, U6.6 (VOUTA)
unnamed: R42.1, U6.7 (VOUTB)
unnamed: R38.2, R39.1, R40.2, U7.4 (ADJ)
unnamed: C27.1, C29.1, L13.1, R39.2, U7.5 (VOUT)
unnamed: C32.1, U8.2 (CAP+)
unnamed: C32.2, U8.4 (CAP-)

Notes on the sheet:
Rotary Encoder 2
RF Input
Fans
Txvr Interface
DC Fan
PWM Fan 1
ALC
RF_BYPASS
Serial
RF_AMPLIFY
PWM Fan 3
Rotary Encoder 1
PWM Fan 2
Analog Inputs from Directional Couplers 0 to 3.3V
Power
Meters
WS2812
Pi Pico Power Output 3.3V 300mA
I2C

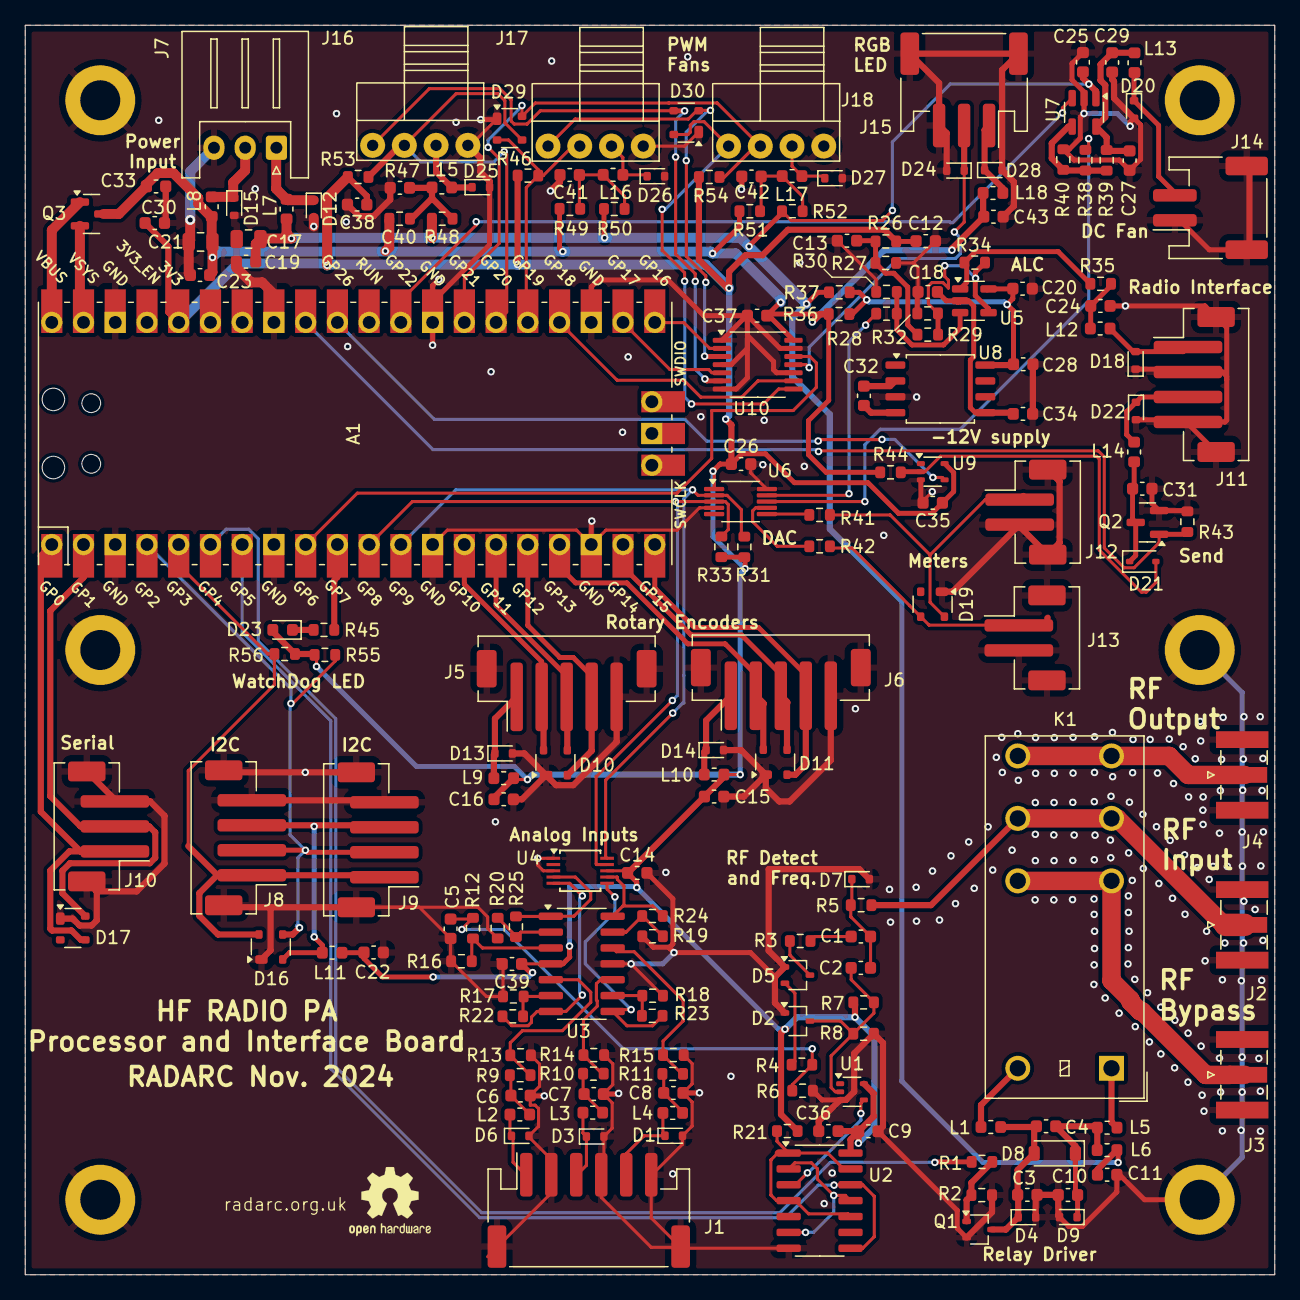
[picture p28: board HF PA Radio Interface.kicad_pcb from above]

Board: 2 copper layers, 100.0 x 100.0 mm, 187 parts (0 on the bottom side), 105 nets.

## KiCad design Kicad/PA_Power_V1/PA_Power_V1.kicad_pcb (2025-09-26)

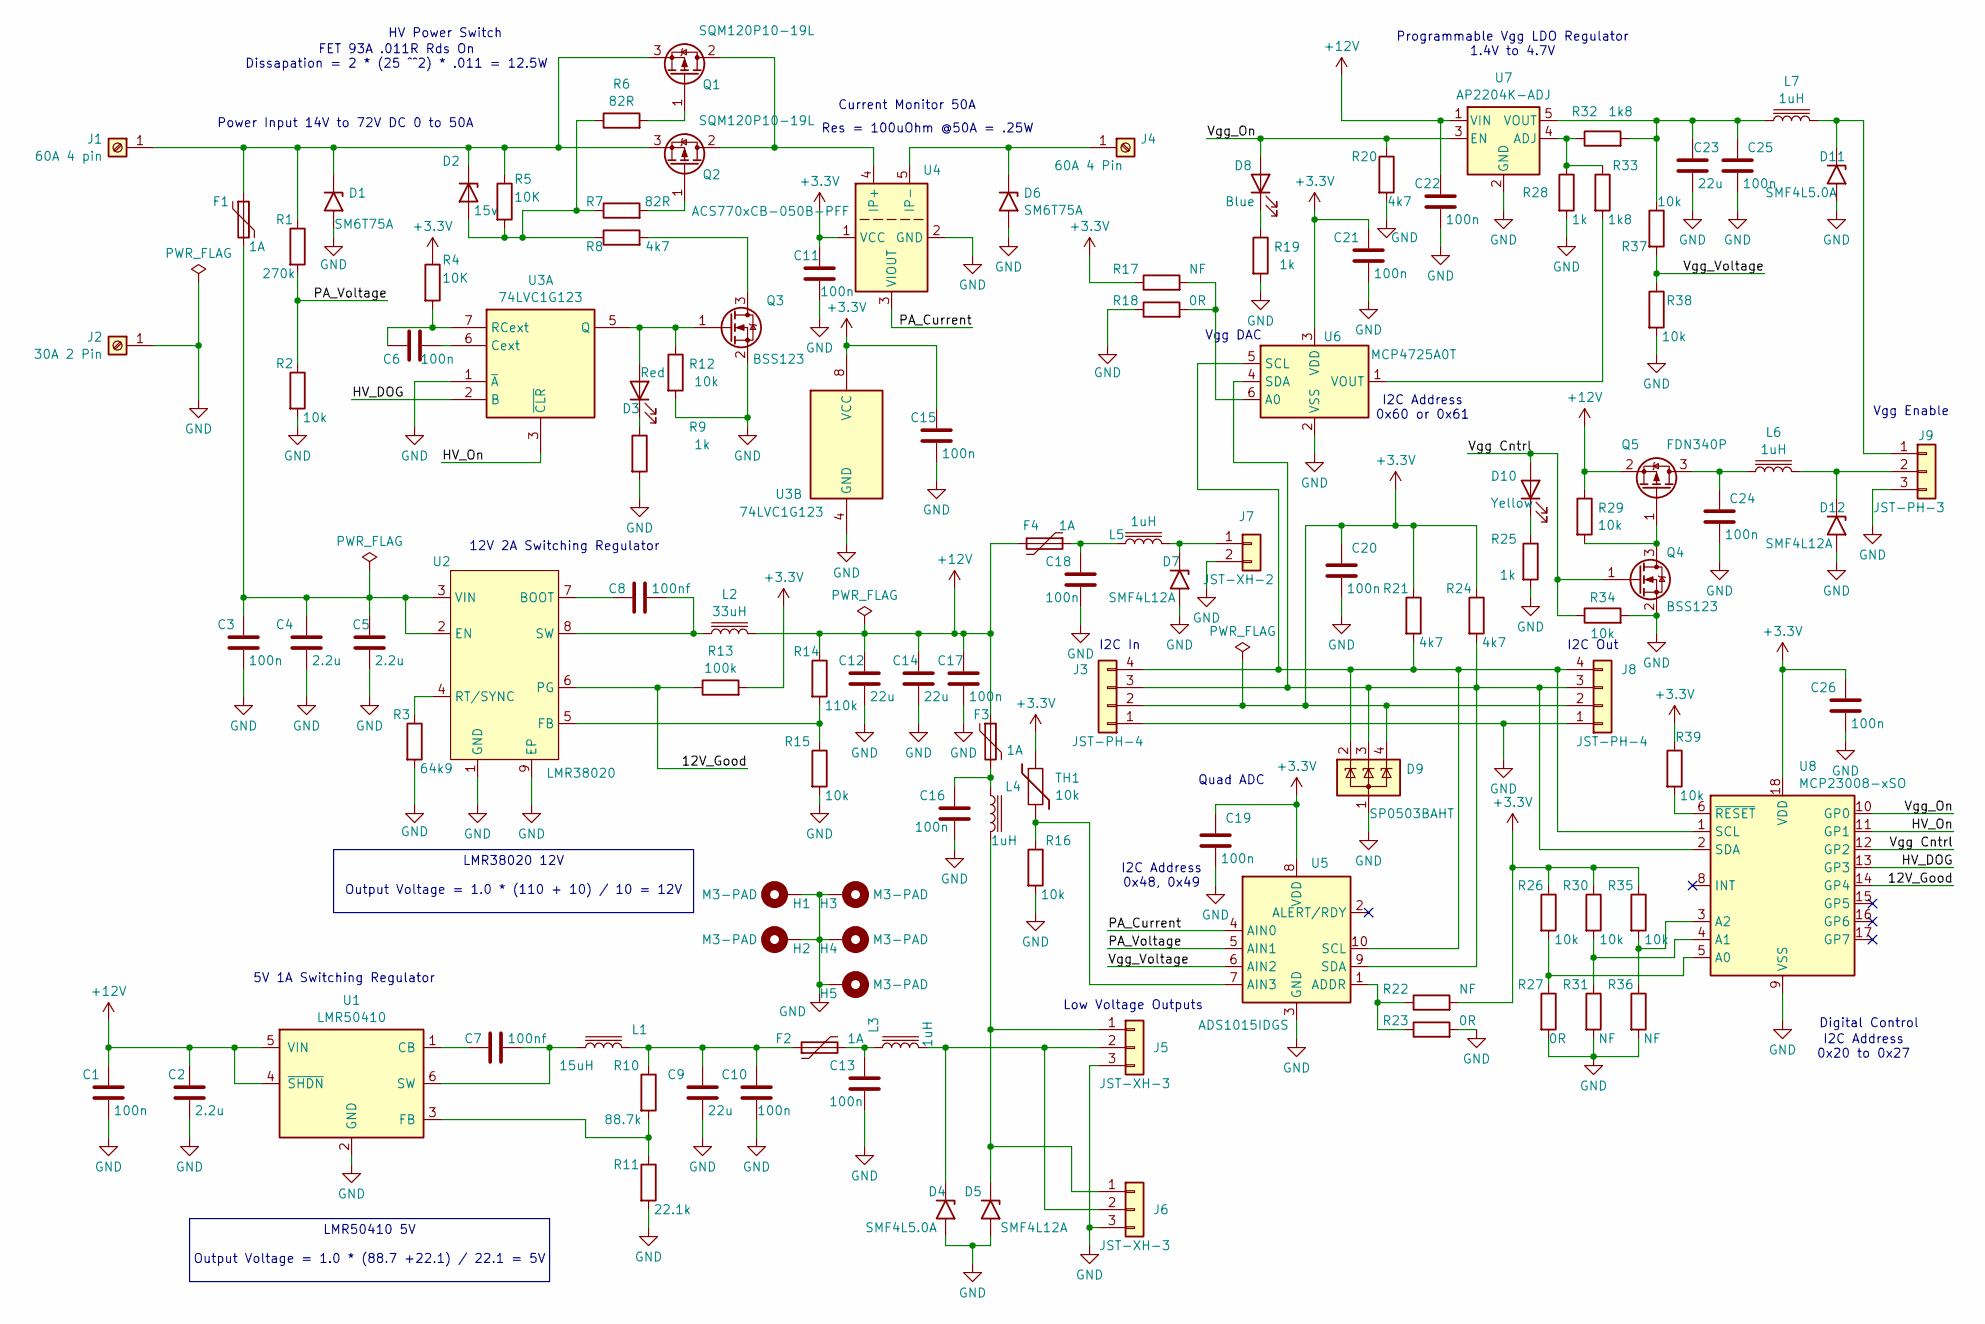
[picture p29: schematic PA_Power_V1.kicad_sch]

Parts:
C1, C10, C11, C13, C15, C16, C17, C18, C19, C20, C21, C22, C24, C25, C26: 100n; C_0603_1608Metric
C2: 2.2u; C_0603_1608Metric
C3, C6: 100n; C_0805_2012Metric
C4, C5: 2.2u; C_1210_3225Metric
C7, C8: 100nf; C_0603_1608Metric
C9, C12, C14: 22u; C_1210_3225Metric
C23: 22u; C_0805_2012Metric
D1, D6: SM6T75A; D_SMB
D2: 15v; Nexperia_CFP3_SOD-123W
D3: Red; LED_0603_1608Metric
D4, D11: SMF4L5.0A; D_SOD-123F
D5, D7, D12: SMF4L12A; D_SOD-123F
D8: Blue; LED_0603_1608Metric
D9: SP0503BAHT; SOT-143
D10: Yellow; LED_0603_1608Metric
F1: 1A; Fuse_Schurter_UMZ250
F2, F3, F4: 1A; Fuse_1812_4532Metric
H1, H2, H3, H4, H5: M3-PAD; MountingHole_3.2mm_M3_DIN965_Pad
J1: 60A 4 pin; Fat_Power 4
J2: 30A 2 Pin; Fat_Power 2
J3, J8: JST-PH-4; JST_PH_B4B-PH-SM4-TB_1x04-1MP_P2.00mm_Vertical
J4: 60A 4 Pin; Fat_Power 4
J5, J6: JST-XH-3; JST_XH_S3B-XH-A_1x03_P2.50mm_Horizontal
J7: JST-XH-2; JST_XH_S2B-XH-A_1x02_P2.50mm_Horizontal
J9: JST-PH-3; JST_PH_S3B-PH-SM4-TB_1x03-1MP_P2.00mm_Horizontal
L1: 15uH; L_Wuerth_MAPI-4030
L2: 33uH; L_Coilcraft_MSS1210-XXX
L3, L4, L5, L6, L7: 1uH; L_0805_2012Metric
Q1, Q2: SQM120P10-19L; TO263_Heatsink_301
Q3, Q4: BSS123; SOT-23
Q5: FDN340P; SOT-23
R1: 270k; R_0603_1608Metric
R2, R12, R15, R16, R26, R29, R30, R34, R35, R37, R38, R39: 10k; R_0603_1608Metric
R3: 64k9; R_0603_1608Metric
R4, R5: 10K; R_0603_1608Metric
R6, R7: 82R; R_0603_1608Metric
R8, R20, R21, R24: 4k7; R_0603_1608Metric
R9, R19, R25, R28: 1k; R_0603_1608Metric
R10: 88.7k; R_0603_1608Metric
R11: 22.1k; R_0603_1608Metric
R13: 100k; R_0603_1608Metric
R14: 110k; R_0603_1608Metric
R17, R22, R31, R36: NF; R_0603_1608Metric
R18, R23, R27: 0R; R_0603_1608Metric
R32, R33: 1k8; R_0603_1608Metric
TH1: 10k; R_0603_1608Metric
U1: LMR50410; SOT-23-6
U2: LMR38020; lmr38012
U3: 74LVC1G123; SSOP-8_2.95x2.8mm_P0.65mm
U4: ACS770xCB-050B-PFF; Allegro_CB_PFF
U5: ADS1015IDGS; VSSOP-10_3x3mm_P0.5mm
U6: MCP4725A0T; SOT-23-6
U7: AP2204K-ADJ; SOT-23-5
U8: MCP23008-xSO; SOIC-18W_7.5x11.6mm_P1.27mm

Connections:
+3.3V: C11.1, C15.1, C19.1, C20.1, C21.1, C26.1, D9.4 (K), J3.2, J8.2, R4.1, R13.2, R17.1, R21.1, R22.2, R24.1, R26.1, R30.1, R35.1, R39.1, TH1.1, U3.8 (VCC), U4.1 (VCC), U5.8 (VDD), U6.3 (VDD), U8.18 (VDD)
+12V: C1.1, C2.1, C12.1, C14.1, C17.1, C22.1, F3.1, F4.2, L2.2, Q5.2 (S), R14.1, R29.1, U1.4 (~SHDN), U1.5 (VIN), U7.1 (VIN)
/12V_Good: R13.1, U2.6 (PG), U8.14 (GP4)
/HV_DOG: U3.2 (B), U8.13 (GP3)
/HV_On: U3.3 (~CLR), U8.11 (GP1)
/PA_Current: U4.3 (VIOUT), U5.4 (AIN0)
/PA_Voltage: R1.2, R2.1, U5.5 (AIN1)
/Vgg Cntrl: D10.2 (A), Q4.1 (G), R34.1, U8.12 (GP2)
/Vgg_On: D8.2 (A), R20.1, U7.3 (EN), U8.10 (GP0)
/Vgg_Voltage: R37.2, R38.1, U5.6 (AIN2)
GND: C1.2, C2.2, C3.2, C4.2, C5.2, C9.2, C10.2, C11.2, C12.2, C13.2, C14.2, C15.2, C16.2, C17.2, C18.2, C19.2, C20.2, C21.2, C22.2, C23.2, C24.2, C25.2, C26.2, D1.2 (A2), D4.2 (A2), D5.2 (A2), D6.2 (A2), D7.2 (A2), D9.1 (A), D11.2 (A2), D12.2 (A2), H1.1, H2.1, H3.1, H4.1, H5.1, J2.1, J3.1, J5.3, J6.3, J7.2, J8.1, J9.3, Q3.2 (S), Q4.2 (S), R2.2, R3.2, R9.2, R11.2, R12.2, R15.2, R16.2, R18.1, R19.2, R20.2, R23.2, R25.2, R27.2, R28.2, R31.2, R34.2, R36.2, R38.2, U1.2 (GND), U2.1 (GND), U2.9 (EP), U3.1 (~A), U3.4 (GND), U4.2 (GND), U5.3 (GND), U6.2 (VSS), U7.2 (GND), U8.9 (VSS)
unnamed: C9.1, C10.1, F2.1, L1.2, R10.1
unnamed: C13.1, F2.2, L3.1
unnamed: C16.1, F3.2, L4.1
unnamed: C18.1, F4.1, L5.1
unnamed: D1.1 (A1), D2.1 (K), F1.1, J1.1, Q1.3 (S), Q2.3 (S), R1.1, R5.1
unnamed: D2.2 (A), R5.2, R6.1, R7.1, R8.1
unnamed: D3.2 (A), Q3.1 (G), R12.1, U3.5 (Q)
unnamed: D3.1 (K), R9.1
unnamed: D4.1 (A1), J5.2, J6.2, L3.2
unnamed: D5.1 (A1), J5.1, J6.1, L4.2
unnamed: D6.1 (A1), J4.1, U4.5 (IP-)
unnamed: D7.1 (A1), J7.1, L5.2
unnamed: D8.1 (K), R19.1
unnamed: D10.1 (K), R25.1
unnamed: D11.1 (A1), J9.1, L7.2
unnamed: D12.1 (A1), J9.2, L6.2
unnamed: D9.3 (K), J3.3, J8.3, R24.2, U5.9 (SDA), U6.4 (SDA), U8.2 (SDA)
unnamed: D9.2 (K), J3.4, J8.4, R21.2, U5.10 (SCL), U6.5 (SCL), U8.1 (SCL)
unnamed: Q1.2 (D), Q2.2 (D), U4.4 (IP+)
unnamed: Q1.1 (G), R6.2
unnamed: Q2.1 (G), R7.2
unnamed: Q3.3 (D), R8.2
unnamed: Q4.3 (D), Q5.1 (G), R29.2
unnamed: C24.1, L6.1, Q5.3 (D)
unnamed: C7.1, U1.1 (CB)
unnamed: R10.2, R11.1, U1.3 (FB)
unnamed: C7.2, L1.1, U1.6 (SW)
unnamed: C8.1, U2.7 (BOOT)
unnamed: C3.1, C4.1, C5.1, F1.2, U2.2 (EN), U2.3 (VIN)
unnamed: R14.2, R15.1, U2.5 (FB)
unnamed: R3.1, U2.4 (RT/SYNC)
unnamed: C8.2, L2.1, U2.8 (SW)
unnamed: C6.2, U3.6 (Cext)
unnamed: C6.1, R4.2, U3.7 (RCext)
unnamed: R22.1, R23.1, U5.1 (ADDR)
unnamed: R16.1, TH1.2, U5.7 (AIN3)
unnamed: R17.2, R18.2, U6.6 (A0)
unnamed: R33.2, U6.1 (VOUT)
unnamed: R28.1, R32.1, R33.1, U7.4 (ADJ)
unnamed: C23.1, C25.1, L7.1, R32.2, R37.1, U7.5 (VOUT)
unnamed: R26.2, R27.1, U8.5 (A0)
unnamed: R30.2, R31.1, U8.4 (A1)
unnamed: R35.2, R36.1, U8.3 (A2)
unnamed: R39.2, U8.6 (~RESET)

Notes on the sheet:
5V 1A Switching Regulator
Current Monitor 50A
Quad ADC
Digital Control
I2C Out
Res = 100uOhm @50A = .25W
LMR38020 12V Output Voltage = 1.0 * (110 + 10) / 10 = 12V
Low Voltage Outputs
I2C In
HV Power Switch
LMR50410 5V Output Voltage = 1.0 * (88.7 +22.1) / 22.1 = 5V
I2C Address 0x20 to 0x27
Vgg Enable
FET 93A .011R Rds On Dissapation = 2 * (25 ^^2) * .011 = 12.5W
12V 2A Switching Regulator
Vgg DAC
I2C Address 0x60 or 0x61
Power Input 14V to 72V DC 0 to 50A
I2C Address 0x48, 0x49
Programmable Vgg LDO Regulator 1.4V to 4.7V

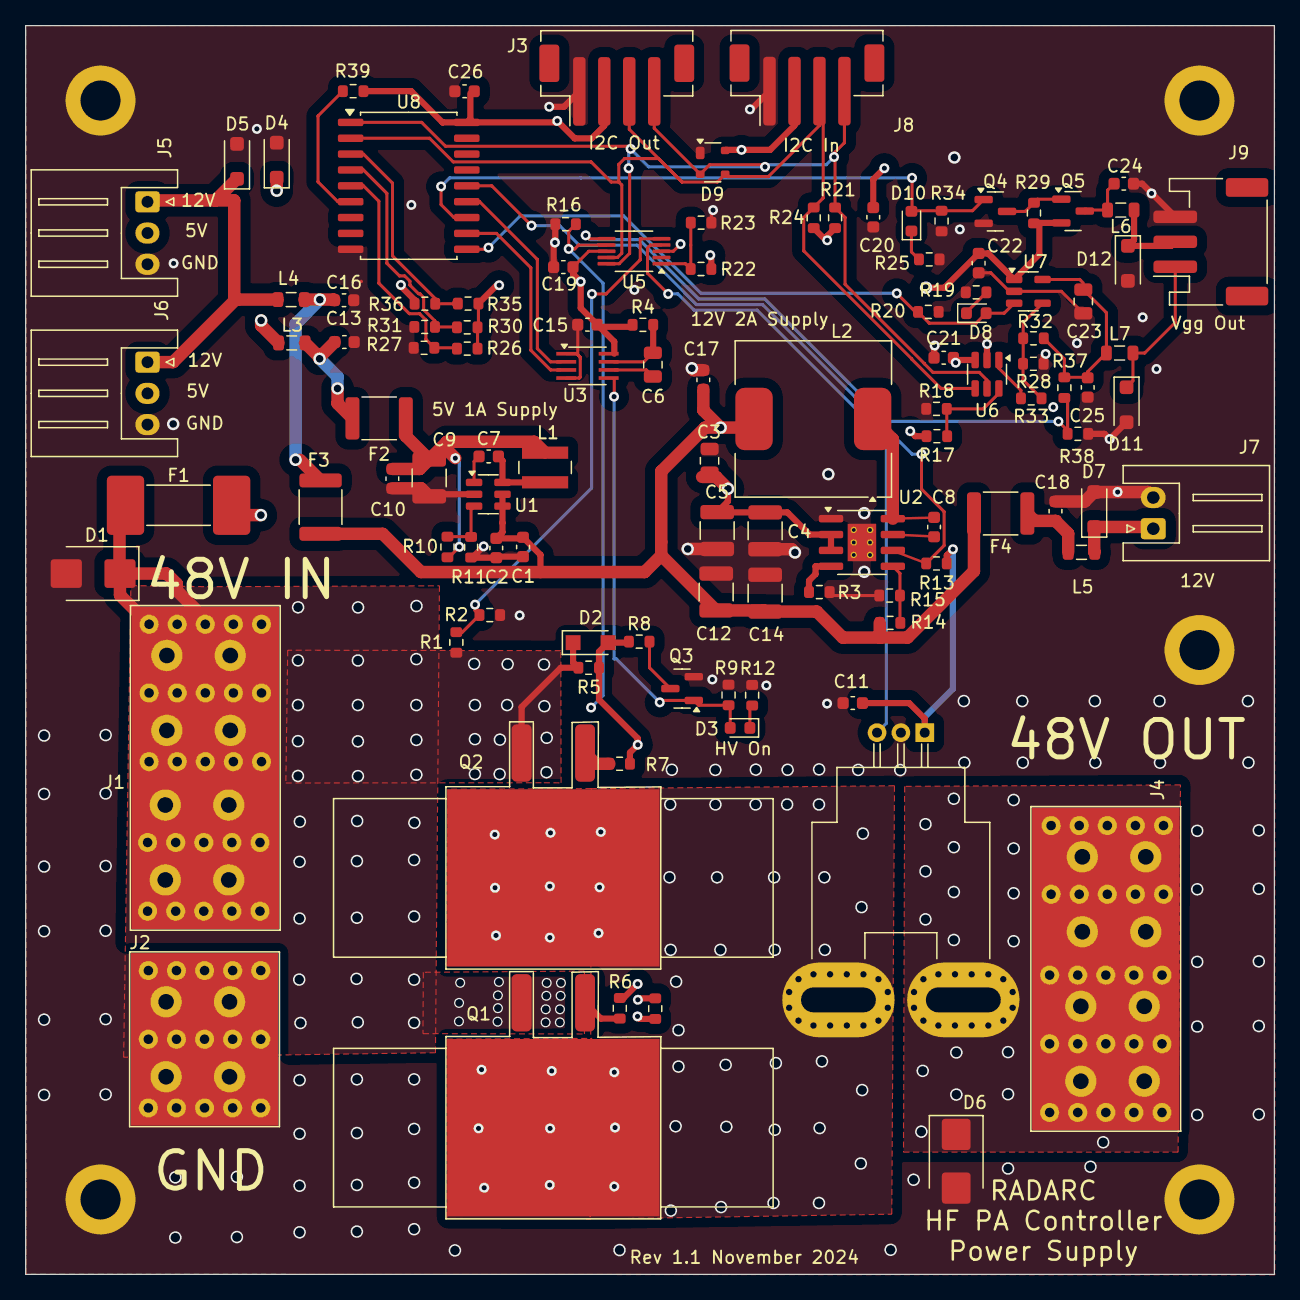
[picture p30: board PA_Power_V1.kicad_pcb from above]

Board: 4 copper layers, 100.0 x 100.0 mm, 116 parts (0 on the bottom side), 55 nets.

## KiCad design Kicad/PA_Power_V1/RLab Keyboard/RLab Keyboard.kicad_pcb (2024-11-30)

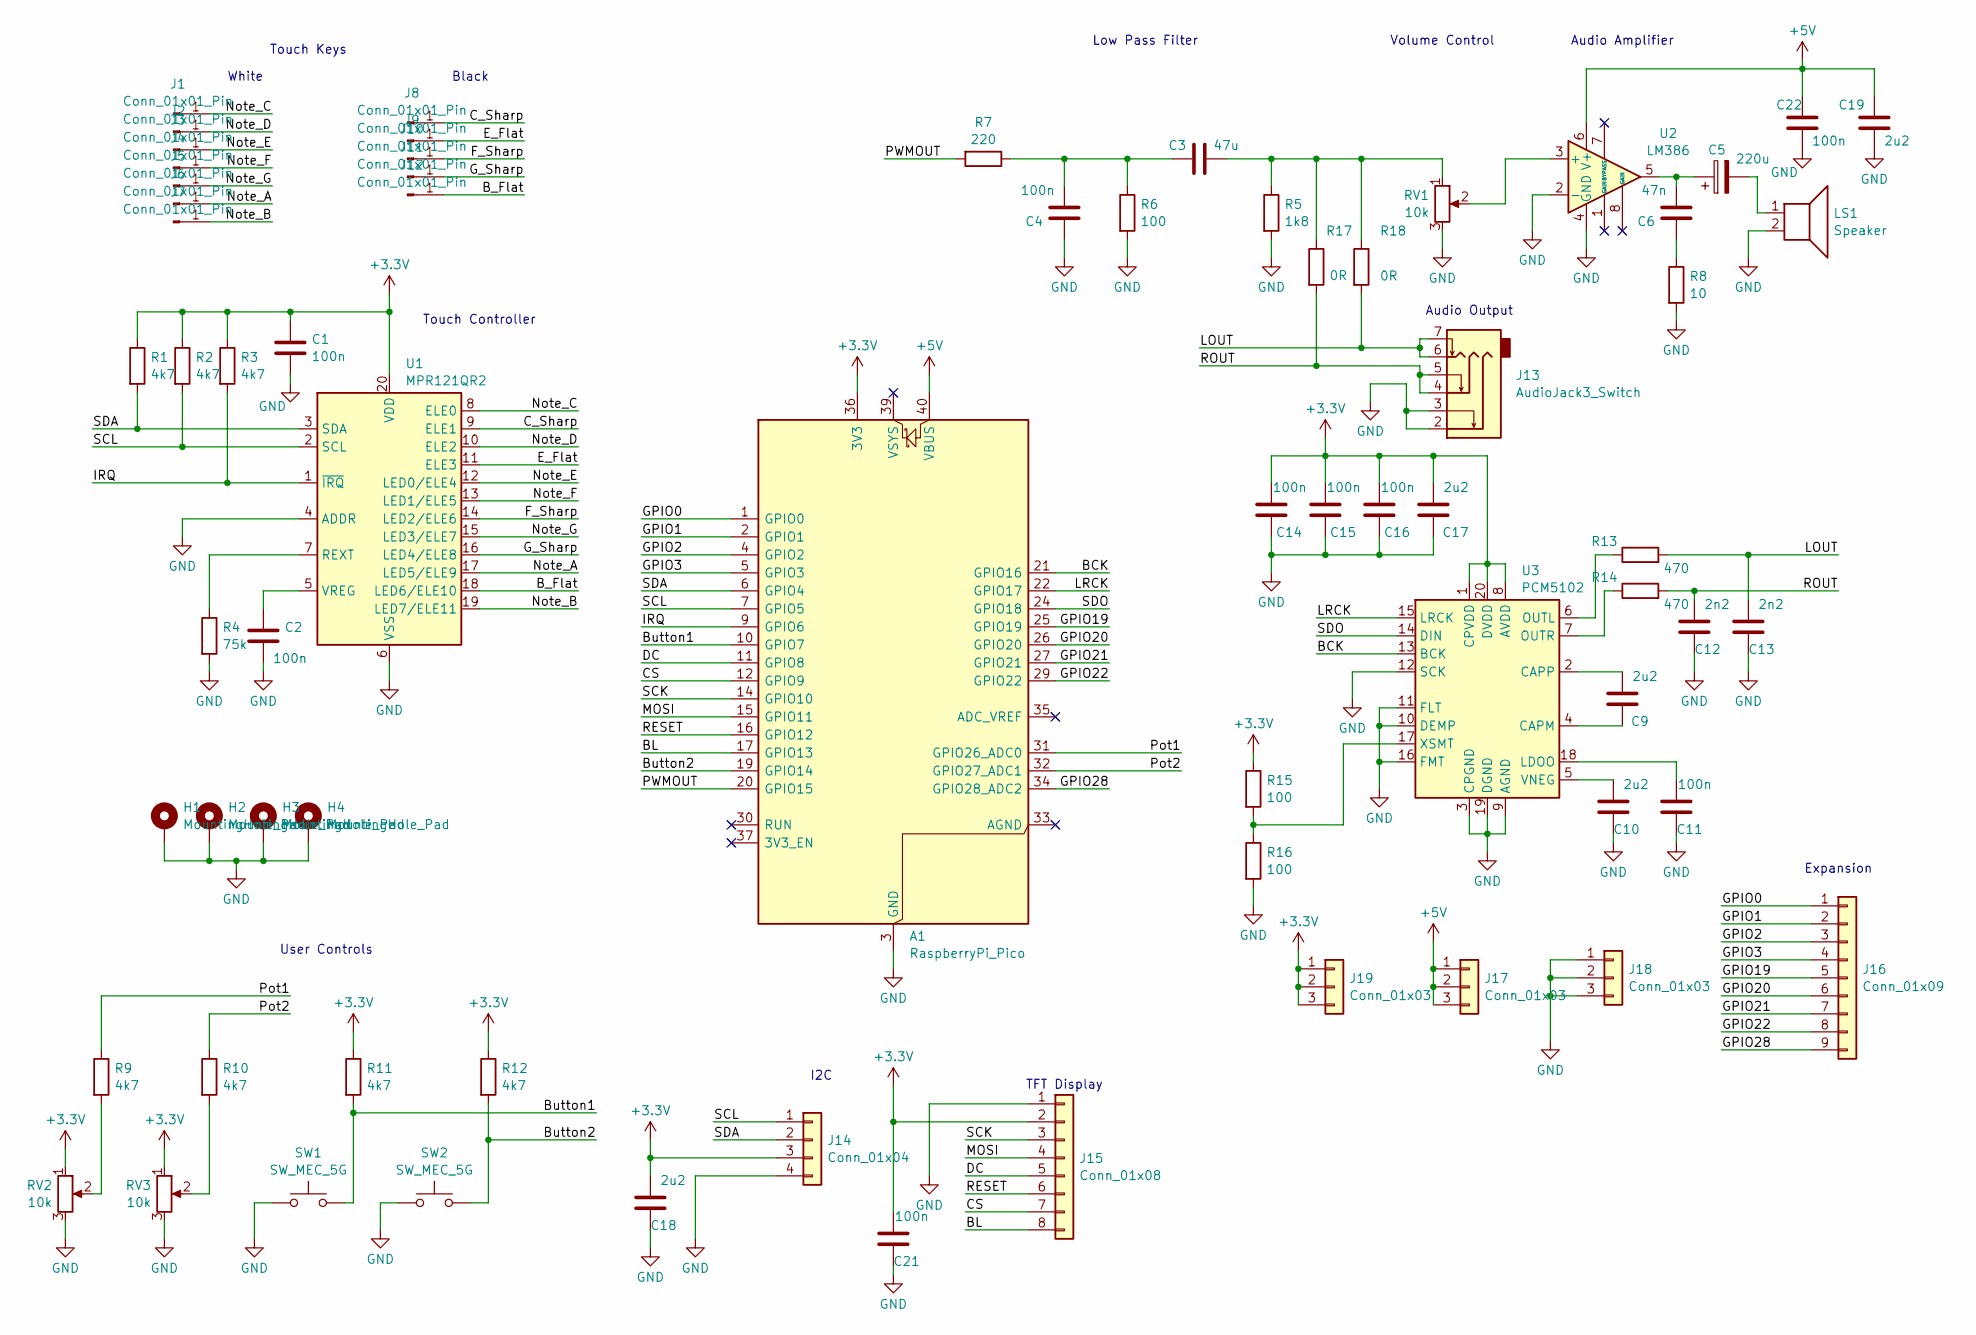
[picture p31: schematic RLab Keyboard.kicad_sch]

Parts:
A1: RaspberryPi_Pico; RPi_Pico_SMD_TH
C1, C2, C4, C11, C14, C15, C16, C21, C22: 100n; C_0603_1608Metric
C3: 47u; C_0805_2012Metric
C5: 220u; C_1206_3216Metric
C6: 47n; C_0603_1608Metric
C9, C10, C17, C18, C19: 2u2; C_0603_1608Metric
C12, C13: 2n2; C_0603_1608Metric
H1, H2, H3, H4: MountingHole_Pad; MountingHole_2.2mm_M2_DIN965_Pad
J1, J2, J3, J4, J5, J6, J7: Conn_01x01_Pin; White_Key
J8, J9, J10, J11, J12: Conn_01x01_Pin; Black_key
J13: AudioJack3_Switch; Jack_3.5mm_PJ342_Horizontal
J14: Conn_01x04; PinSocket_1x04_P2.54mm_Vertical
J15: Conn_01x08; PinSocket_1x08_P2.54mm_Vertical
J16: Conn_01x09; PinSocket_1x09_P2.54mm_Vertical
J17, J18, J19: Conn_01x03; PinSocket_1x03_P2.54mm_Vertical
LS1: Speaker; 30mm_Speaker
R1, R2, R3, R9, R10, R11, R12: 4k7; R_0603_1608Metric
R4: 75k; R_0603_1608Metric
R5: 1k8; R_0603_1608Metric
R6, R15, R16: 100; R_0603_1608Metric
R7: 220; R_0603_1608Metric
R8: 10; R_0603_1608Metric
R13, R14: 470; R_0603_1608Metric
R17, R18: 0R; R_0603_1608Metric
RV1: 10k; Potentiometer_Bourns_3214G_Horizontal
RV2, RV3: 10k; Potentiometer_Alps_RK09K_Single_Vertical
SW1, SW2: SW_MEC_5G; SW_PUSH_6mm_H5mm
U1: MPR121QR2; UQFN-20_3x3mm_P0.4mm
U2: LM386; SOIC-8_3.9x4.9mm_P1.27mm
U3: PCM5102; TSSOP-20_4.4x6.5mm_P0.65mm

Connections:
+3.3V: A1.36 (3V3), C1.1, C14.2, C15.2, C16.2, C17.2, C18.2, C21.2, J14.3, J15.2, J19.1, J19.2, J19.3, R1.1, R2.1, R3.1, R11.1, R12.1, R15.1, RV2.1, RV3.1, U1.20 (VDD), U3.1 (CPVDD), U3.8 (AVDD), U3.20 (DVDD)
+5V: A1.40 (VBUS), C19.2, C22.1, J17.1, J17.2, J17.3, U2.6 (V+)
/BCK: A1.21 (GPIO16), U3.13 (BCK)
/BL: A1.17 (GPIO13), J15.8
/B_Flat: J12.1, U1.18 (LED6/ELE10)
/Button1: A1.10 (GPIO7), R11.2, SW1.2
/Button2: A1.19 (GPIO14), R12.2, SW2.2
/CS: A1.12 (GPIO9), J15.7
/C_Sharp: J8.1, U1.9 (ELE1)
/DC: A1.11 (GPIO8), J15.5
/E_Flat: J9.1, U1.11 (ELE3)
/F_Sharp: J10.1, U1.14 (LED2/ELE6)
/GPIO0: A1.1 (GPIO0), J16.1
/GPIO1: A1.2 (GPIO1), J16.2
/GPIO2: A1.4 (GPIO2), J16.3
/GPIO3: A1.5 (GPIO3), J16.4
/GPIO19: A1.25 (GPIO19), J16.5
/GPIO20: A1.26 (GPIO20), J16.6
/GPIO21: A1.27 (GPIO21), J16.7
/GPIO22: A1.29 (GPIO22), J16.8
/GPIO28: A1.34 (GPIO28_ADC2), J16.9
/G_Sharp: J11.1, U1.16 (LED4/ELE8)
/IRQ: A1.9 (GPIO6), R3.2, U1.1 (~IRQ)
/LOUT: C13.2, J13.6, J13.7, R13.2, R18.2
/LRCK: A1.22 (GPIO17), U3.15 (LRCK)
/MOSI: A1.15 (GPIO11), J15.4
/Note_A: J6.1, U1.17 (LED5/ELE9)
/Note_B: J7.1, U1.19 (LED7/ELE11)
/Note_C: J1.1, U1.8 (ELE0)
/Note_D: J2.1, U1.10 (ELE2)
/Note_E: J3.1, U1.12 (LED0/ELE4)
/Note_F: J4.1, U1.13 (LED1/ELE5)
/Note_G: J5.1, U1.15 (LED3/ELE7)
/PWMOUT: A1.20 (GPIO15), R7.2
/Pot1: A1.31 (GPIO26_ADC0), R9.1
/Pot2: A1.32 (GPIO27_ADC1), R10.1
/RESET: A1.16 (GPIO12), J15.6
/ROUT: C12.2, J13.4, J13.5, R14.2, R17.2
/SCK: A1.14 (GPIO10), J15.3
/SCL: A1.7 (GPIO5), J14.1, R2.2, U1.2 (SCL)
/SDA: A1.6 (GPIO4), J14.2, R1.2, U1.3 (SDA)
/SDO: A1.24 (GPIO18), U3.14 (DIN)
GND: A1.3 (GND), A1.8 (GND), A1.13 (GND), A1.18 (GND), A1.23 (GND), A1.28 (GND), A1.38 (GND), C1.2, C2.2, C4.1, C10.1, C11.1, C12.1, C13.1, C14.1, C15.1, C16.1, C17.1, C18.1, C19.1, C21.1, C22.2, H1.1, H2.1, H3.1, H4.1, J13.2, J13.3, J14.4, J15.1, J18.1, J18.2, J18.3, LS1.2, R4.2, R5.2, R6.2, R8.2, R16.2, RV1.3, RV2.3, RV3.3, SW1.1, SW2.1, U1.4 (ADDR), U1.6 (VSS), U2.2 (-), U2.4 (GND), U3.3 (CPGND), U3.9 (AGND), U3.10 (DEMP), U3.11 (FLT), U3.12 (SCK), U3.16 (FMT), U3.19 (DGND)
unnamed: C3.1, R5.1, R17.1, R18.1, RV1.1
unnamed: C3.2, C4.2, R6.1, R7.1
unnamed: C5.1, C6.2, U2.5
unnamed: C5.2, LS1.1
unnamed: C6.1, R8.1
unnamed: R9.2, RV2.2
unnamed: R10.2, RV3.2
unnamed: R4.1, U1.7 (REXT)
unnamed: C2.1, U1.5 (VREG)
unnamed: RV1.2, U2.3 (+)
unnamed: C9.1, U3.4 (CAPM)
unnamed: C9.2, U3.2 (CAPP)
unnamed: C11.2, U3.18 (LDOO)
unnamed: R13.1, U3.6 (OUTL)
unnamed: R14.1, U3.7 (OUTR)
unnamed: C10.2, U3.5 (VNEG)
unnamed: R15.2, R16.1, U3.17 (XSMT)

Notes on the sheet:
Low Pass Filter
Black
Touch Keys
Audio Amplifier
Audio Output
TFT Display
Volume Control
I2C
Expansion
User Controls
Touch Controller
White

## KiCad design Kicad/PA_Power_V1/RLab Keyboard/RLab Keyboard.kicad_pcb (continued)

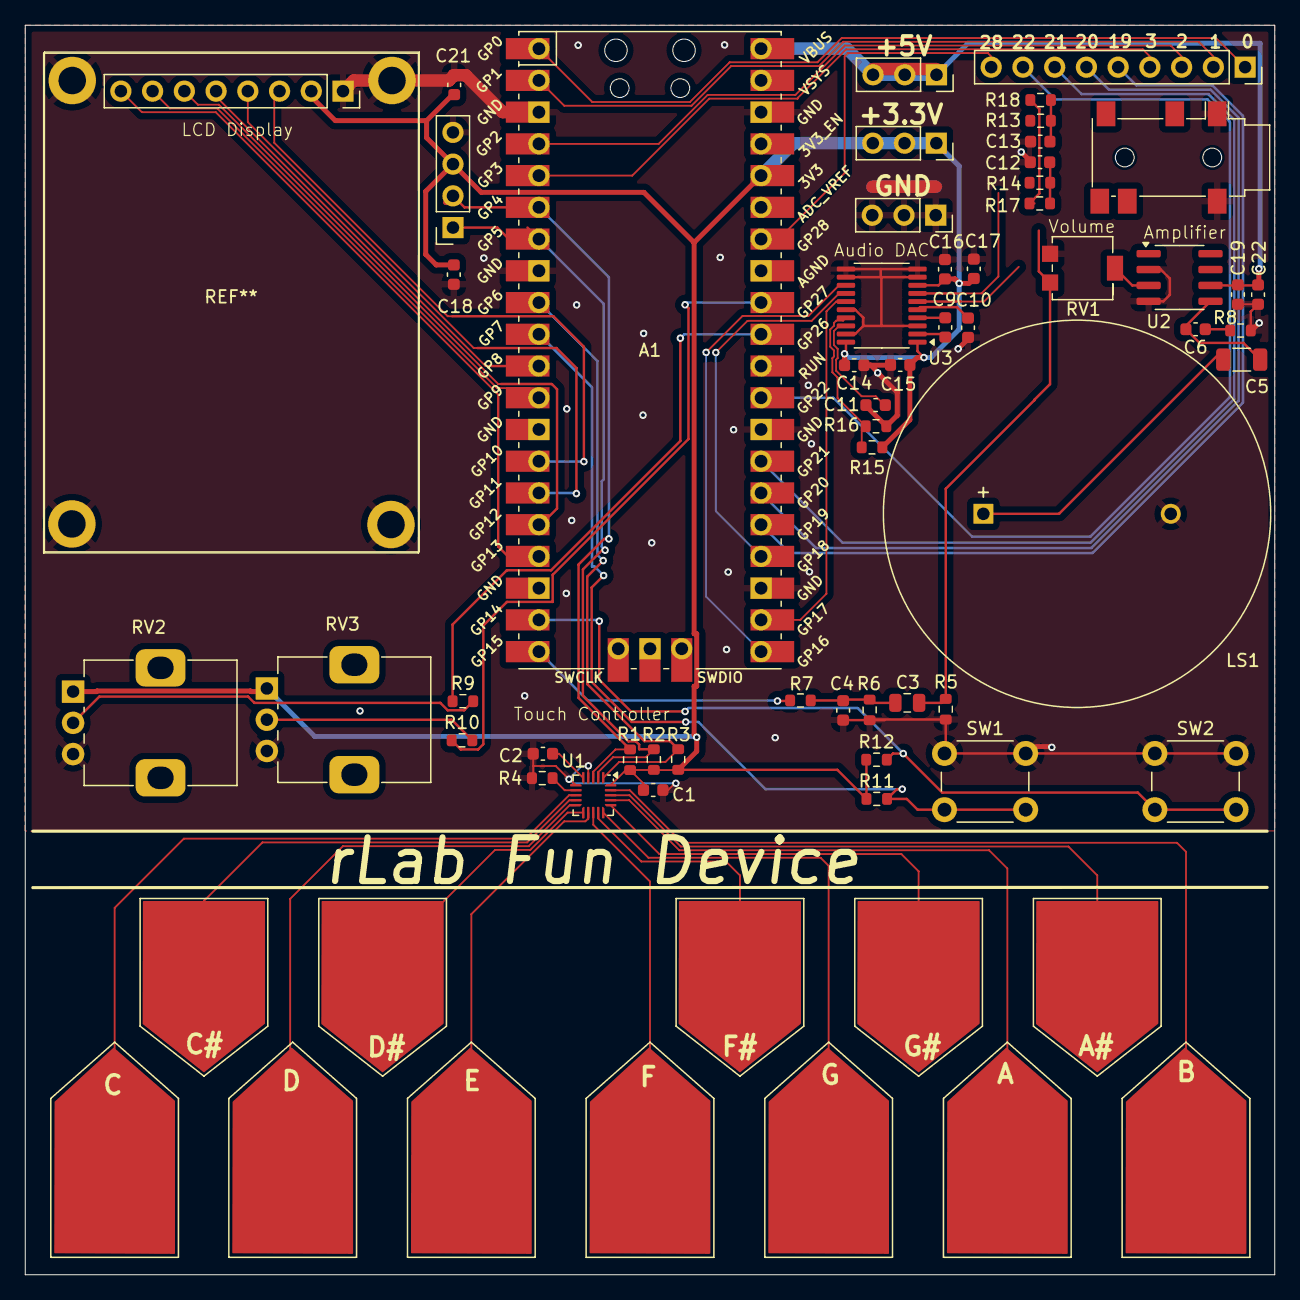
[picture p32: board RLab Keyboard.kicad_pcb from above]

Board: 2 copper layers, 100.0 x 100.0 mm, 70 parts (0 on the bottom side), 60 nets.

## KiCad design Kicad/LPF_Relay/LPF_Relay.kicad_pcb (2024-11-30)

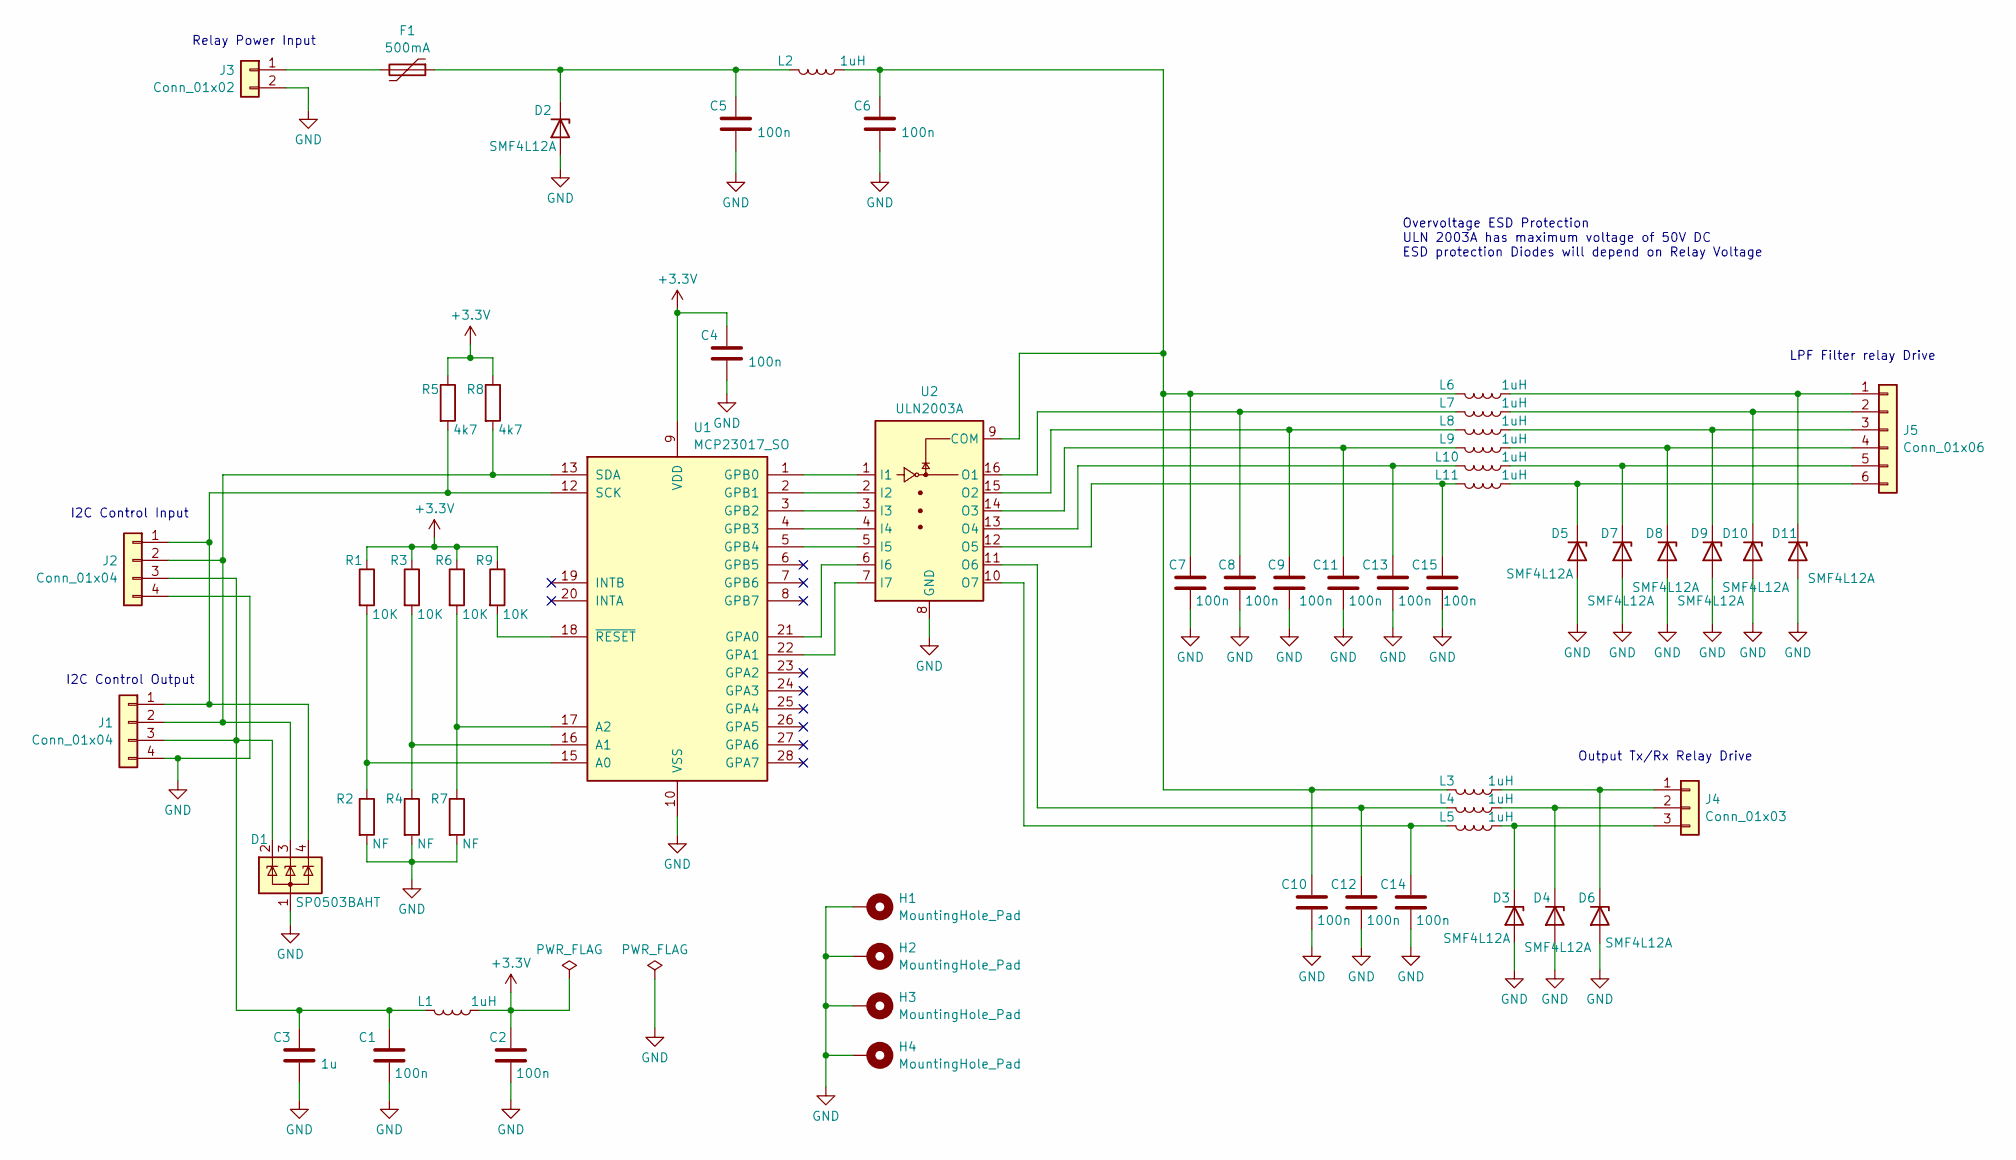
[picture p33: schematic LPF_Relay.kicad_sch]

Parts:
C1, C2, C4, C5, C6, C7, C8, C9, C10, C11, C12, C13, C14, C15: 100n; C_0603_1608Metric
C3: 1u; C_0603_1608Metric
D1: SP0503BAHT; SOT-143
D2, D3, D4, D5, D6, D7, D8, D9, D10, D11: SMF4L12A; D_SOD-123F
F1: 500mA; Fuse_0805_2012Metric
H1, H2, H3, H4: MountingHole_Pad; MountingHole_3.2mm_M3_DIN965_Pad
J1, J2: Conn_01x04; JST_PH_S4B-PH-SM4-TB_1x04-1MP_P2.00mm_Horizontal
J3: Conn_01x02; JST_XH_S2B-XH-A-1_1x02_P2.50mm_Horizontal
J4: Conn_01x03; JST_XH_S3B-XH-A-1_1x03_P2.50mm_Horizontal
J5: Conn_01x06; JST_XH_S6B-XH-A-1_1x06_P2.50mm_Horizontal
L1, L2, L3, L4, L5, L6, L7, L8, L9, L10, L11: 1uH; L_0603_1608Metric
R1, R3, R6, R9: 10K; R_0603_1608Metric
R2, R4, R7: NF; R_0603_1608Metric
R5, R8: 4k7; R_0603_1608Metric
U1: MCP23017_SO; SSOP-28_5.3x10.2mm_P0.65mm
U2: ULN2003A; SO-16_3.9x9.9mm_P1.27mm

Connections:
+3.3V: C2.1, C4.1, L1.1, R1.1, R3.1, R5.1, R6.1, R8.1, R9.1, U1.9 (VDD)
GND: C1.2, C2.2, C3.2, C4.2, C5.2, C6.2, C7.2, C8.2, C9.2, C10.2, C11.2, C12.2, C13.2, C14.2, C15.2, D1.1 (A), D2.2 (A), D3.2 (A), D4.2 (A), D5.2 (A), D6.2 (A), D7.2 (A), D8.2 (A), D9.2 (A), D10.2 (A), D11.2 (A), H1.1, H2.1, H3.1, H4.1, J1.4, J2.4, J3.2, R2.2, R4.2, R7.2, U1.10 (VSS), U2.8 (GND)
unnamed: C5.1, D2.1 (K), F1.1, L2.2
unnamed: D3.1 (K), J4.3, L5.1
unnamed: D4.1 (K), J4.2, L4.1
unnamed: D5.1 (K), J5.6, L11.1
unnamed: D6.1 (K), J4.1, L3.1
unnamed: D7.1 (K), J5.5, L10.1
unnamed: D8.1 (K), J5.4, L9.1
unnamed: D9.1 (K), J5.3, L8.1
unnamed: D10.1 (K), J5.2, L7.1
unnamed: D11.1 (K), J5.1, L6.1
unnamed: D1.4 (K), J1.1, J2.1, R5.2, U1.12 (SCK)
unnamed: D1.3 (K), J1.2, J2.2, R8.2, U1.13 (SDA)
unnamed: C1.1, C3.1, D1.2 (K), J1.3, J2.3, L1.2
unnamed: F1.2, J3.1
unnamed: R1.2, R2.1, U1.15 (A0)
unnamed: R3.2, R4.1, U1.16 (A1)
unnamed: R6.2, R7.1, U1.17 (A2)
unnamed: U1.21 (GPA0), U2.6 (I6)
unnamed: U1.22 (GPA1), U2.7 (I7)
unnamed: U1.1 (GPB0), U2.1 (I1)
unnamed: U1.2 (GPB1), U2.2 (I2)
unnamed: U1.3 (GPB2), U2.3 (I3)
unnamed: U1.4 (GPB3), U2.4 (I4)
unnamed: U1.5 (GPB4), U2.5 (I5)
unnamed: R9.2, U1.18 (~RESET)
unnamed: C6.1, C7.1, C10.1, L2.1, L3.2, L6.2, U2.9 (COM)
unnamed: C8.1, L7.2, U2.16 (O1)
unnamed: C9.1, L8.2, U2.15 (O2)
unnamed: C11.1, L9.2, U2.14 (O3)
unnamed: C13.1, L10.2, U2.13 (O4)
unnamed: C15.1, L11.2, U2.12 (O5)
unnamed: C12.1, L4.2, U2.11 (O6)
unnamed: C14.1, L5.2, U2.10 (O7)

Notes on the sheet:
I2C Control Output
LPF Filter relay Drive
Output Tx/Rx Relay Drive
I2C Control Input
Relay Power Input
Overvoltage ESD Protection ULN 2003A has maximum voltage of 50V DC ESD protection Diodes will depend on Relay Voltage

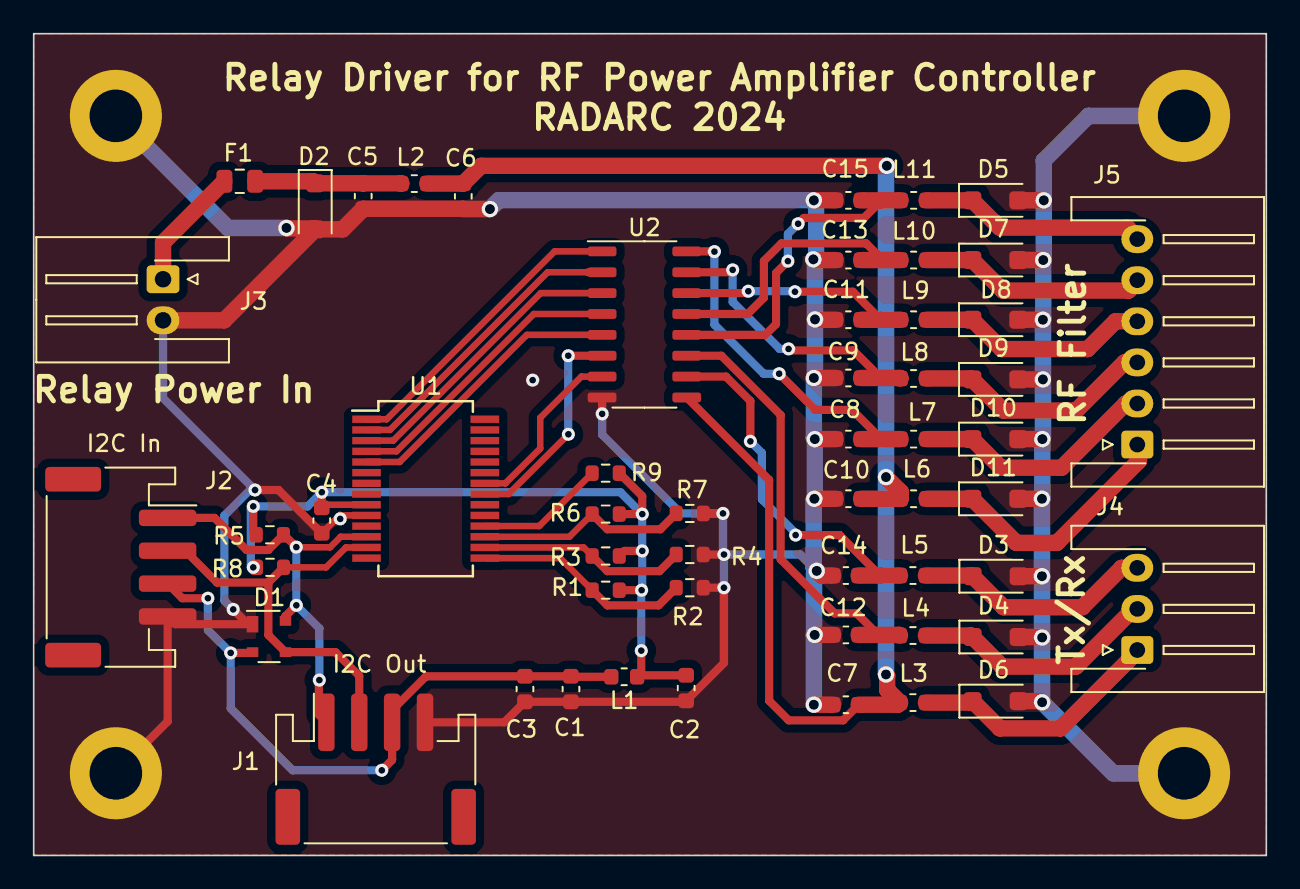
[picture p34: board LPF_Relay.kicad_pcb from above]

Board: 2 copper layers, 75.0 x 50.0 mm, 58 parts (0 on the bottom side), 35 nets.

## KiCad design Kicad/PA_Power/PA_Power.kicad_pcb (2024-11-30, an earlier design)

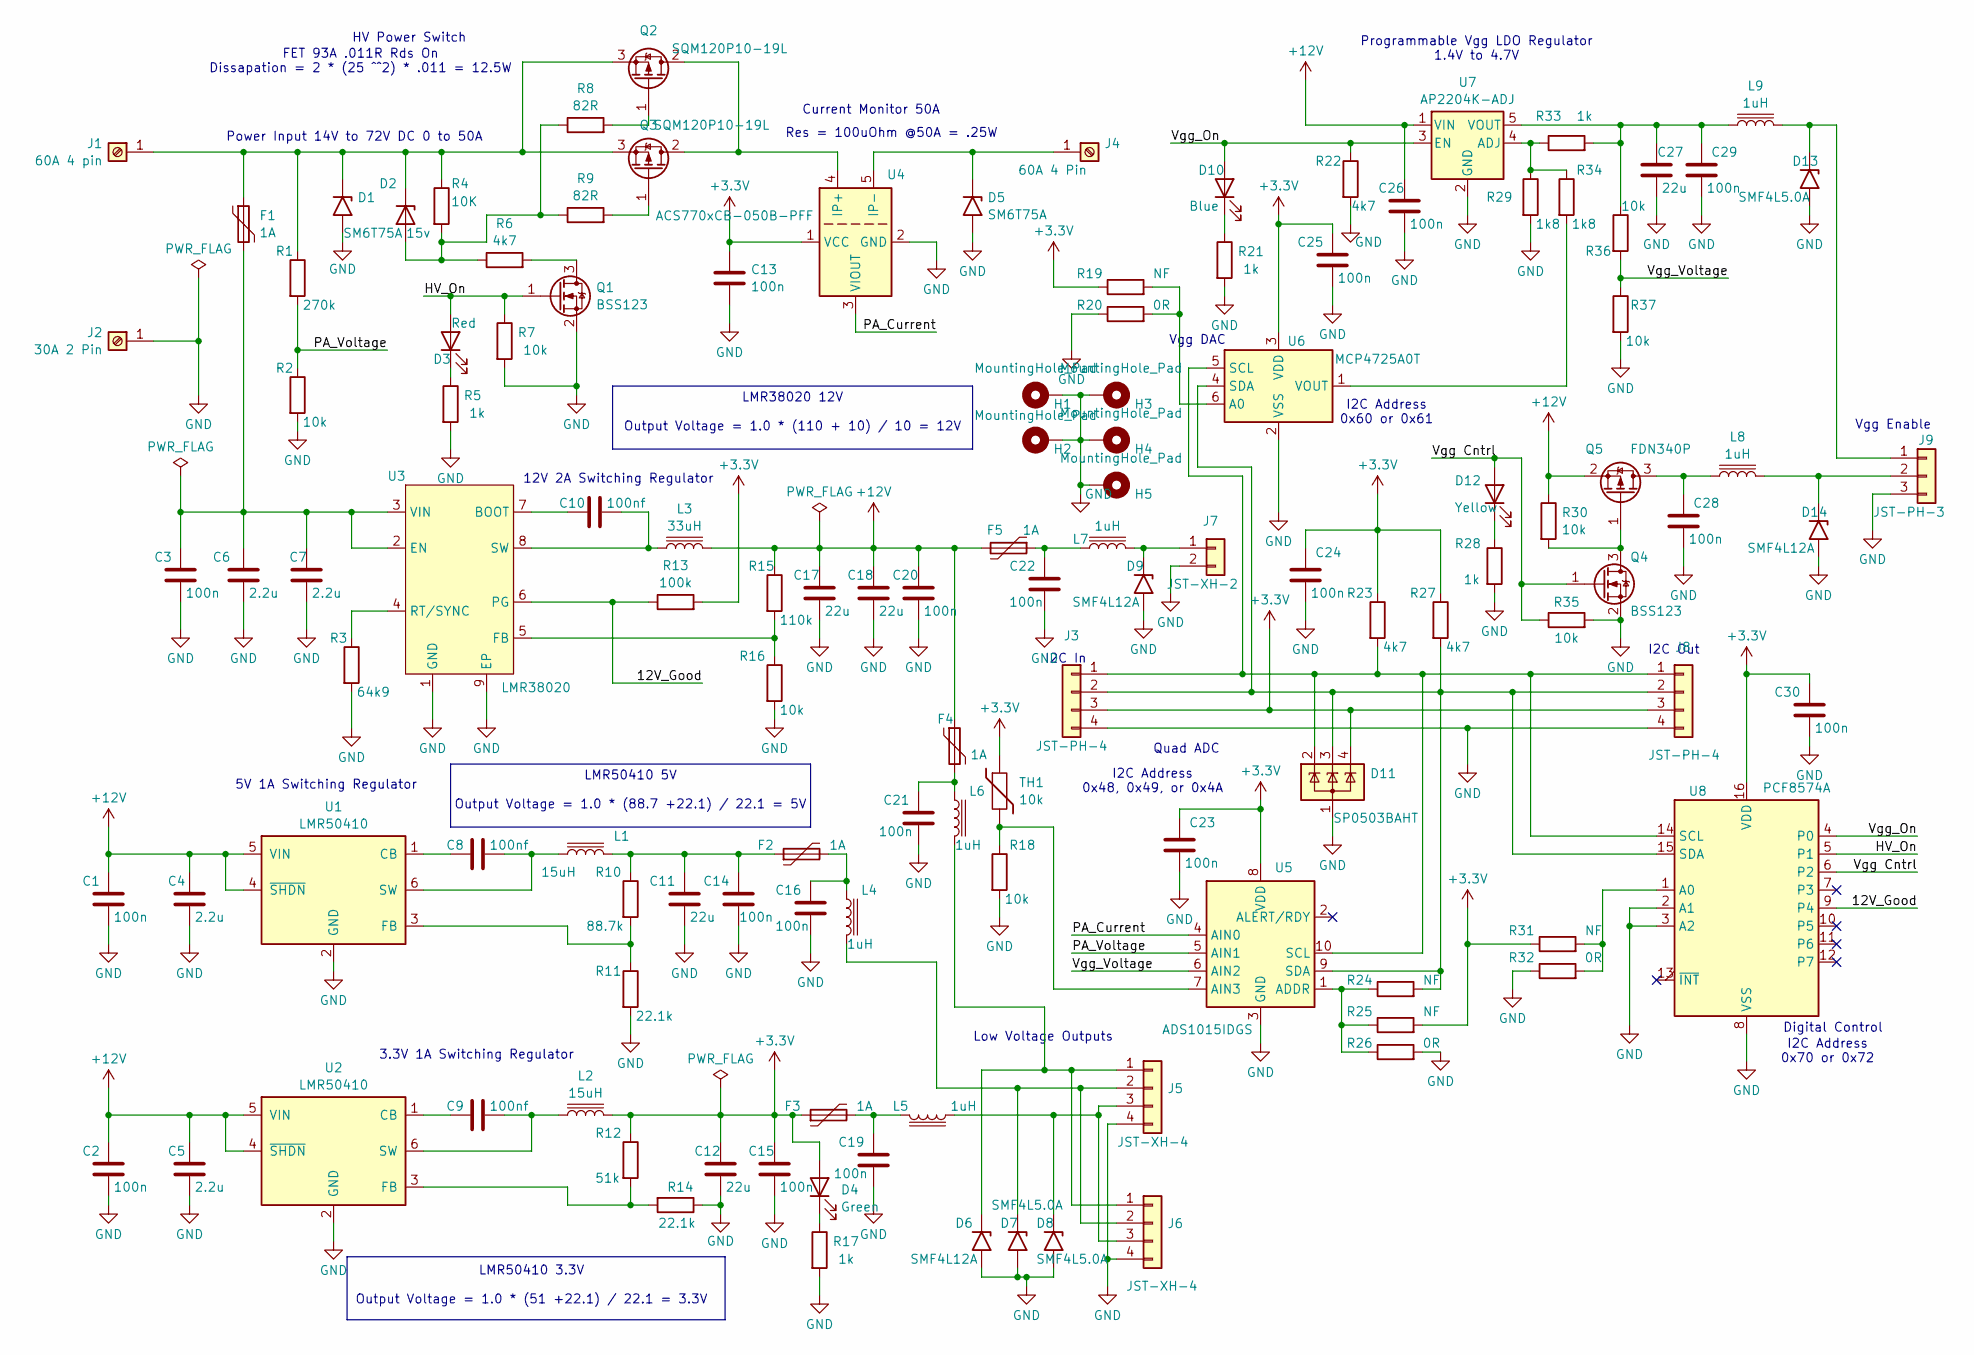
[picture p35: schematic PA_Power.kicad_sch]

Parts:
C1, C2, C13, C14, C15, C16, C19, C20, C21, C22, C23, C24, C25, C26, C28, C29, C30: 100n; C_0603_1608Metric
C3: 100n; C_0805_2012Metric
C4, C5: 2.2u; C_0603_1608Metric
C6, C7: 2.2u; C_1210_3225Metric
C8, C9, C10: 100nf; C_0603_1608Metric
C11, C12, C17, C18: 22u; C_1210_3225Metric
C27: 22u; C_0805_2012Metric
D1, D5: SM6T75A; D_SMB
D2: 15v; Nexperia_CFP3_SOD-123W
D3: Red; LED_0603_1608Metric
D4: Green; LED_0603_1608Metric
D6, D9, D14: SMF4L12A; D_SOD-123F
D7, D8, D13: SMF4L5.0A; D_SOD-123F
D10: Blue; LED_0603_1608Metric
D11: SP0503BAHT; SOT-143
D12: Yellow; LED_0603_1608Metric
F1: 1A; Fuse_Schurter_UMZ250
F2, F3, F4, F5: 1A; Fuse_1812_4532Metric
H1, H2, H3, H4, H5: MountingHole_Pad; MountingHole_3.2mm_M3_DIN965_Pad
J1: 60A 4 pin; Fat_Power 4
J2: 30A 2 Pin; Fat_Power 2
J3, J8: JST-PH-4; JST_PH_B4B-PH-SM4-TB_1x04-1MP_P2.00mm_Vertical
J4: 60A 4 Pin; Fat_Power 4
J5, J6: JST-XH-4; JST_XH_S4B-XH-A_1x04_P2.50mm_Horizontal
J7: JST-XH-2; JST_XH_S2B-XH-A_1x02_P2.50mm_Horizontal
J9: JST-PH-3; JST_PH_S3B-PH-SM4-TB_1x03-1MP_P2.00mm_Horizontal
L1, L2: 15uH; L_Wuerth_MAPI-4030
L3: 33uH; L_Coilcraft_MSS1210-XXX
L4, L5, L6, L7, L8, L9: 1uH; L_0805_2012Metric
Q1, Q4: BSS123; SOT-23
Q2, Q3: SQM120P10-19L; TO263_Heatsink_301
Q5: FDN340P; SOT-23
R1: 270k; R_0603_1608Metric
R2, R7, R16, R18, R30, R35, R36, R37: 10k; R_0603_1608Metric
R3: 64k9; R_0603_1608Metric
R4: 10K; R_0603_1608Metric
R5, R17, R21, R28, R33: 1k; R_0603_1608Metric
R6, R22, R23, R27: 4k7; R_0603_1608Metric
R8, R9: 82R; R_0603_1608Metric
R10: 88.7k; R_0603_1608Metric
R11, R14: 22.1k; R_0603_1608Metric
R12: 51k; R_0603_1608Metric
R13: 100k; R_0603_1608Metric
R15: 110k; R_0603_1608Metric
R19, R24, R25, R31: NF; R_0603_1608Metric
R20, R26, R32: 0R; R_0603_1608Metric
R29, R34: 1k8; R_0603_1608Metric
TH1: 10k; R_0603_1608Metric
U1, U2: LMR50410; SOT-23-6
U3: LMR38020; lmr38012
U4: ACS770xCB-050B-PFF; Allegro_CB_PFF
U5: ADS1015IDGS; TSSOP-10_3x3mm_P0.5mm
U6: MCP4725A0T; SOT-23-6
U7: AP2204K-ADJ; SOT-23-5
U8: PCF8574A; SOIC-16W_7.5x10.3mm_P1.27mm

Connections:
+3.3V: C12.1, C13.1, C15.1, C23.1, C24.1, C25.1, C30.1, D4.2 (A), D11.4 (K), F3.1, J3.3, J8.3, L2.2, R12.1, R13.2, R19.1, R23.1, R25.2, R27.1, R31.1, TH1.1, U4.1 (VCC), U5.8 (VDD), U6.3 (VDD), U8.16 (VDD)
+12V: C1.1, C2.1, C4.1, C5.1, C17.1, C18.1, C20.1, C26.1, F4.1, F5.2, L3.2, Q5.2 (S), R15.1, R30.1, U1.4 (~SHDN), U1.5 (VIN), U2.4 (~SHDN), U2.5 (VIN), U7.1 (VIN)
/12V_Good: R13.1, U3.6 (PG), U8.9 (P4)
/HV_On: D3.2 (A), Q1.1 (G), R7.1, U8.5 (P1)
/PA_Current: U4.3 (VIOUT), U5.4 (AIN0)
/PA_Voltage: R1.2, R2.1, U5.5 (AIN1)
/Vgg Cntrl: D12.2 (A), Q4.1 (G), R35.1, U8.6 (P2)
/Vgg_On: D10.2 (A), R22.1, U7.3 (EN), U8.4 (P0)
/Vgg_Voltage: R36.2, R37.1, U5.6 (AIN2)
GND: C1.2, C2.2, C3.2, C4.2, C5.2, C6.2, C7.2, C11.2, C12.2, C13.2, C14.2, C15.2, C16.2, C17.2, C18.2, C19.2, C20.2, C21.2, C22.2, C23.2, C24.2, C25.2, C26.2, C27.2, C28.2, C29.2, C30.2, D1.2 (A2), D5.2 (A2), D6.2 (A2), D7.2 (A2), D8.2 (A2), D9.2 (A2), D11.1 (A), D13.2 (A2), D14.2 (A2), H1.1, H2.1, H3.1, H4.1, H5.1, J2.1, J3.4, J5.4, J6.4, J7.2, J8.4, J9.3, Q1.2 (S), Q4.2 (S), R2.2, R3.2, R5.2, R7.2, R11.2, R14.1, R16.2, R17.2, R18.2, R20.1, R21.2, R22.2, R26.2, R28.2, R29.2, R32.1, R35.2, R37.2, U1.2 (GND), U2.2 (GND), U3.1 (GND), U3.9 (EP), U4.2 (GND), U5.3 (GND), U6.2 (VSS), U7.2 (GND), U8.2 (A1), U8.3 (A2), U8.8 (VSS)
unnamed: C11.1, C14.1, F2.1, L1.2, R10.1
unnamed: C16.1, F2.2, L4.1
unnamed: C19.1, F3.2, L5.2
unnamed: C21.1, F4.2, L6.1
unnamed: C22.1, F5.1, L7.1
unnamed: D1.1 (A1), D2.1 (K), F1.1, J1.1, Q2.3 (S), Q3.3 (S), R1.1, R4.1
unnamed: D2.2 (A), R4.2, R6.1, R8.1, R9.1
unnamed: D3.1 (K), R5.1
unnamed: D4.1 (K), R17.1
unnamed: D5.1 (A1), J4.1, U4.5 (IP-)
unnamed: D6.1 (A1), J5.1, J6.1, L6.2
unnamed: D7.1 (A1), J5.2, J6.2, L4.2
unnamed: D8.1 (A1), J5.3, J6.3, L5.1
unnamed: D9.1 (A1), J7.1, L7.2
unnamed: D10.1 (K), R21.1
unnamed: D12.1 (K), R28.1
unnamed: D13.1 (A1), J9.1, L9.2
unnamed: D14.1 (A1), J9.2, L8.2
unnamed: D11.2 (K), J3.1, J8.1, R23.2, U5.10 (SCL), U6.5 (SCL), U8.14 (SCL)
unnamed: D11.3 (K), J3.2, J8.2, R24.2, R27.2, U5.9 (SDA), U6.4 (SDA), U8.15 (SDA)
unnamed: Q1.3 (D), R6.2
unnamed: Q2.2 (D), Q3.2 (D), U4.4 (IP+)
unnamed: Q2.1 (G), R8.2
unnamed: Q3.1 (G), R9.2
unnamed: Q4.3 (D), Q5.1 (G), R30.2
unnamed: C28.1, L8.1, Q5.3 (D)
unnamed: C8.1, U1.1 (CB)
unnamed: R10.2, R11.1, U1.3 (FB)
unnamed: C8.2, L1.1, U1.6 (SW)
unnamed: C9.1, U2.1 (CB)
unnamed: R12.2, R14.2, U2.3 (FB)
unnamed: C9.2, L2.1, U2.6 (SW)
unnamed: C10.1, U3.7 (BOOT)
unnamed: C3.1, C6.1, C7.1, F1.2, U3.2 (EN), U3.3 (VIN)
unnamed: R15.2, R16.1, U3.5 (FB)
unnamed: R3.1, U3.4 (RT/SYNC)
unnamed: C10.2, L3.1, U3.8 (SW)
unnamed: R24.1, R25.1, R26.1, U5.1 (ADDR)
unnamed: R18.1, TH1.2, U5.7 (AIN3)
unnamed: R19.2, R20.2, U6.6 (A0)
unnamed: R34.2, U6.1 (VOUT)
unnamed: R29.1, R33.1, R34.1, U7.4 (ADJ)
unnamed: C27.1, C29.1, L9.1, R33.2, R36.1, U7.5 (VOUT)
unnamed: R31.2, R32.2, U8.1 (A0)

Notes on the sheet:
5V 1A Switching Regulator
Current Monitor 50A
Quad ADC
Digital Control
LMR50410 3.3V Output Voltage = 1.0 * (51 +22.1) / 22.1 = 3.3V
I2C Out
Res = 100uOhm @50A = .25W
LMR38020 12V Output Voltage = 1.0 * (110 + 10) / 10 = 12V
Low Voltage Outputs
I2C In
HV Power Switch
LMR50410 5V Output Voltage = 1.0 * (88.7 +22.1) / 22.1 = 5V
I2C Address 0x70 or 0x72
Vgg Enable
FET 93A .011R Rds On Dissapation = 2 * (25 ^^2) * .011 = 12.5W
12V 2A Switching Regulator
3.3V 1A Switching Regulator
Vgg DAC
I2C Address 0x60 or 0x61
Power Input 14V to 72V DC 0 to 50A
I2C Address 0x48, 0x49, or 0x4A
Programmable Vgg LDO Regulator 1.4V to 4.7V

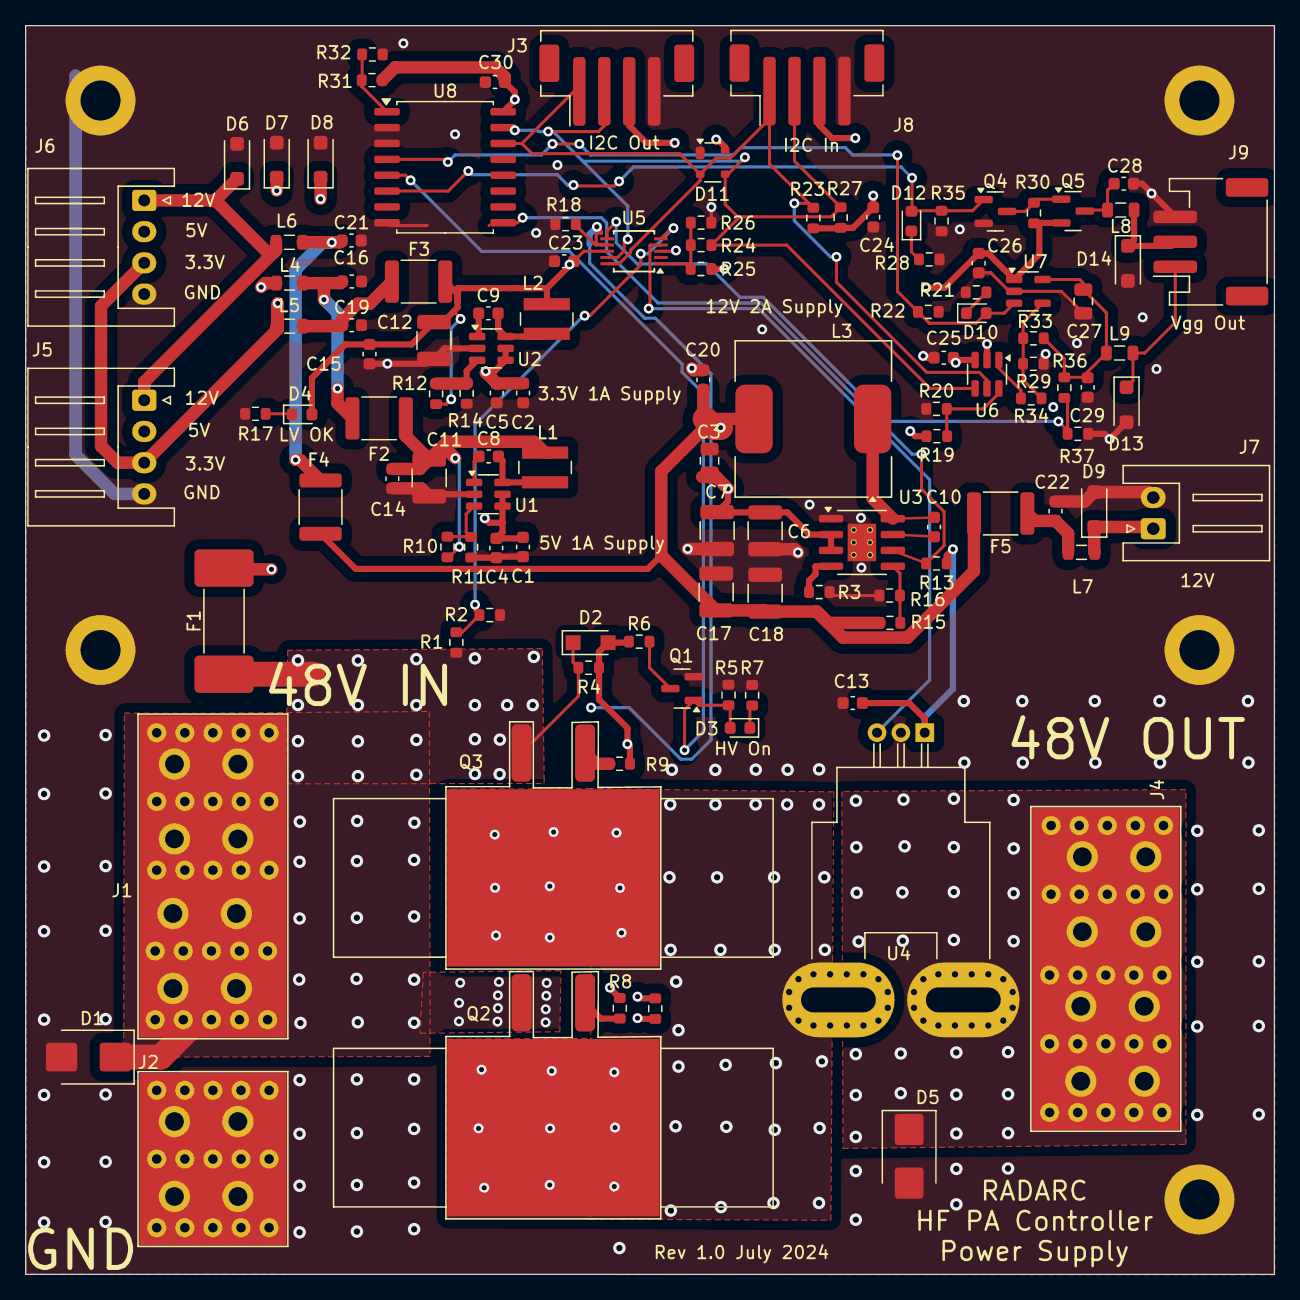
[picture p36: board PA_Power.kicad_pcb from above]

Board: 4 copper layers, 100.0 x 100.0 mm, 123 parts (0 on the bottom side), 54 nets.

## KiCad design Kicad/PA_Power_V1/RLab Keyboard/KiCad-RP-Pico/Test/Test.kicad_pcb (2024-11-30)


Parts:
J1, J2: Conn_01x20; PinSocket_1x20_P1.00mm_Vertical
J3: Conn_01x03; PinSocket_1x03_P1.00mm_Vertical
U1: Pico; RPi_Pico_SMD_TH

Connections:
GND: J1.3, J1.8, J1.13, J1.18, J2.3, J2.13, J2.18, J3.2, U1.3 (GND), U1.8 (GND), U1.13 (GND), U1.18 (GND), U1.23 (GND), U1.28 (GND), U1.38 (GND), U1.42 (GND)
unnamed: J1.1, U1.1 (GPIO0)
unnamed: J1.2, U1.2 (GPIO1)
unnamed: J1.4, U1.4 (GPIO2)
unnamed: J1.5, U1.5 (GPIO3)
unnamed: J1.6, U1.6 (GPIO4)
unnamed: J1.7, U1.7 (GPIO5)
unnamed: J1.9, U1.9 (GPIO6)
unnamed: J1.10, U1.10 (GPIO7)
unnamed: J1.11, U1.11 (GPIO8)
unnamed: J1.12, U1.12 (GPIO9)
unnamed: J1.14, U1.14 (GPIO10)
unnamed: J1.15, U1.15 (GPIO11)
unnamed: J1.16, U1.16 (GPIO12)
unnamed: J1.17, U1.17 (GPIO13)
unnamed: J1.19, U1.19 (GPIO14)
unnamed: J1.20, U1.20 (GPIO15)
unnamed: J2.1, U1.40 (VBUS)
unnamed: J2.2, U1.39 (VSYS)
unnamed: J2.4, U1.37 (3V3_EN)
unnamed: J2.5, U1.36 (3V3)
unnamed: J2.6, U1.35 (ADC_VREF)
unnamed: J2.7, U1.34 (GPIO28_ADC2)
unnamed: J2.8, U1.33 (AGND)
unnamed: J2.9, U1.32 (GPIO27_ADC1)
unnamed: J2.10, U1.31 (GPIO26_ADC0)
unnamed: J2.11, U1.30 (RUN)
unnamed: J2.12, U1.29 (GPIO22)
unnamed: J2.14, U1.27 (GPIO21)
unnamed: J2.15, U1.26 (GPIO20)
unnamed: J2.16, U1.25 (GPIO19)
unnamed: J2.17, U1.24 (GPIO18)
unnamed: J2.19, U1.22 (GPIO17)
unnamed: J2.20, U1.21 (GPIO16)
unnamed: J3.1, U1.43 (SWDIO)
unnamed: J3.3, U1.41 (SWCLK)


Board: 2 copper layers, 43.0 x 65.0 mm, 4 parts (0 on the bottom side), 36 nets.

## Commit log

2024-11-30 First commit of Kicad files
    [1.3 TFT IPS.stp, 3214G.stp, 3314G1.stp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]
2025-09-26 Updates to HF PA Interface and PA Power_V1
    [HF PA Radio Interface.kicad_pcb, HF PA Radio Interface.kicad_sch, PA_Power_V1.kicad_pcb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]
